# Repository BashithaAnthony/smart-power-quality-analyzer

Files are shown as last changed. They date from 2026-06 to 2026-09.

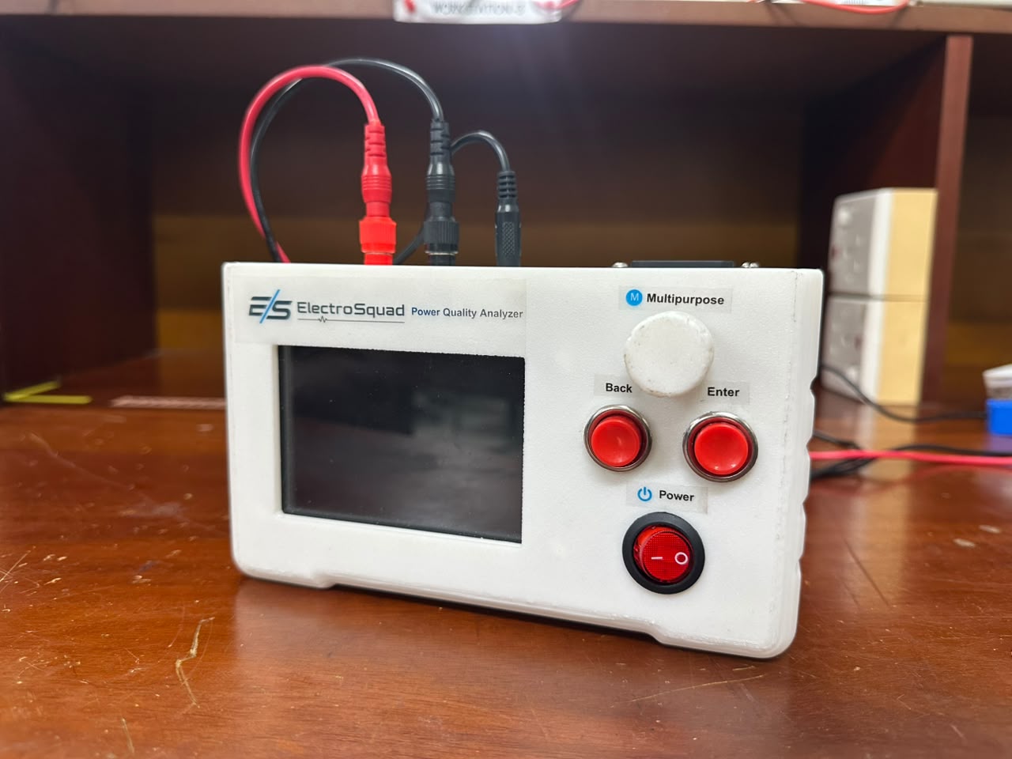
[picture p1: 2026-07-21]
media/image_1.jpeg

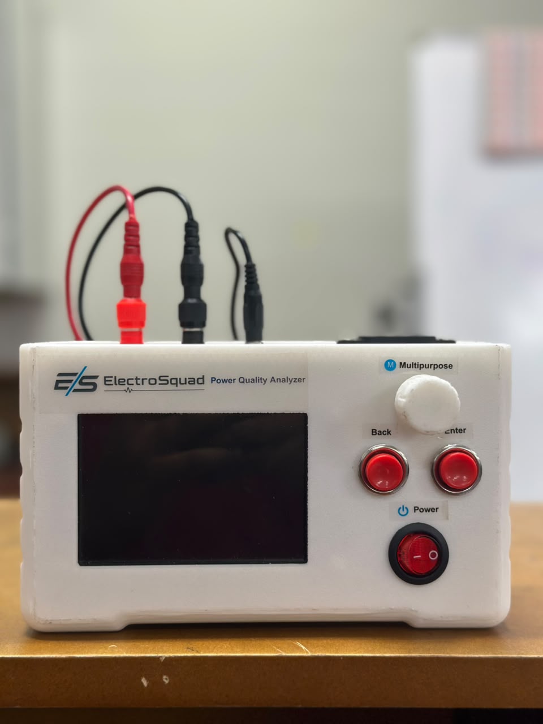
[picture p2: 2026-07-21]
media/image_3.jpeg

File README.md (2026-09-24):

# Smart Power Quality Analyzer

## Overview

The Smart Power Quality Analyzer is an embedded measurement and monitoring system developed for real-time analysis of electrical power quality in single-phase AC power systems. The device continuously acquires voltage and current waveforms, performs high-speed digital signal processing, and provides comprehensive power quality parameters through an intuitive graphical user interface and wireless monitoring platform.

The system is designed around a dual-microcontroller architecture consisting of an STM32F4 as the primary real-time processing unit and an ESP32-S3 dedicated to user interface management, wireless communication, and data visualization. By separating deterministic signal processing from networking and display tasks, the analyzer achieves high measurement accuracy while maintaining a responsive user interface.

The project combines precision analog signal conditioning, high-speed data acquisition, embedded DSP algorithms, graphical visualization, PCB design, and IoT connectivity into a single integrated platform suitable for laboratory, industrial, and educational applications.

# Key Features

## Electrical Measurements

- True RMS voltage measurement
- True RMS current measurement
- Active power calculation
- Reactive power calculation
- Apparent power calculation
- Power factor measurement
- Grid frequency measurement
- Phase angle calculation

## Power Quality Analysis

- Fast Fourier Transform (FFT) based spectral analysis
- Total Harmonic Distortion (THD) calculation
- Individual harmonic magnitude analysis
- Harmonic spectrum visualization
- Real-time waveform monitoring
- Voltage and current waveform comparison
- Continuous sampling and processing

## User Interface

- 4-inch SPI TFT LCD graphical display
- Rotary encoder based navigation
- Physical control buttons for menu navigation
- Real-time waveform rendering
- Live numerical parameter display
- Interactive graphical user interface
- Adjustable display brightness

## Connectivity

- Wi-Fi connectivity
- UART communication between STM32 and ESP32
- Remote monitoring
- Web-based dashboard
- Wireless data transfer
- MicroSD card support for future data logging

## Embedded System Features

- High-speed ADC sampling
- Real-time DSP processing
- Interrupt-driven firmware
- Multi-tasking architecture
- High-speed UART communication
- Hardware PWM control
- DMA-based data acquisition
- Efficient memory management

# System Architecture

The analyzer is divided into two independent processing sections.

## STM32F4 Processing Unit

Responsible for:

- High-speed ADC sampling
- Analog signal acquisition
- Digital filtering
- FFT computation
- RMS calculations
- Power calculations
- Harmonic analysis
- Frequency estimation
- Real-time data processing
- Communication with ESP32

## ESP32-S3 Interface Unit

Responsible for:

- LCD graphics rendering
- User interface management
- Rotary encoder handling
- Push-button interface
- Wi-Fi communication
- Web server communication
- Remote monitoring
- Data visualization
- System configuration

# Hardware Overview

## Analog Front-End

- Voltage sensing circuitry
- Current sensing circuitry
- Signal conditioning
- Precision operational amplifiers
- Anti-aliasing filters
- ADC input protection

## Processing Hardware

### STM32F4

- Primary real-time processing controller
- Digital signal processing
- High-speed ADC operation
- FFT execution
- Measurement calculations

### ESP32-S3

- Dual-core processor
- Integrated Wi-Fi
- TFT display controller
- Human-machine interface
- Wireless communication

## Display

- 4.0-inch SPI TFT LCD
- Real-time waveform visualization
- Menu-based graphical interface
- Adjustable LED backlight

## User Controls

- Incremental rotary encoder
- Enter button
- Back button
- System power control
- On-screen navigation

## Power System

- High-efficiency buck converters
- Low-noise analog supplies
- Dedicated digital power rails
- Ferrite-bead power filtering
- Controlled power sequencing
- Push-button power management

# Signal Processing

The system continuously samples voltage and current waveforms using the STM32F4 ADC.

The acquired samples undergo several DSP stages including:

- Offset correction
- Noise filtering
- Windowing
- FFT transformation
- Harmonic extraction
- RMS computation
- Frequency estimation
- Power calculations
- THD computation

The processed information is transmitted to the ESP32-S3 for visualization and wireless communication.

# Communication Architecture

## STM32 ↔ ESP32

Communication is performed through UART interface, providing reliable high-speed data transfer between the processing unit and the user interface module.

Transmitted data includes:

- Voltage samples
- Current samples
- RMS measurements
- Frequency
- Power factor
- Harmonic information
- THD values
- System status

## ESP32 ↔ User

The ESP32 provides:

- Graphical LCD interface
- Local parameter display
- Wi-Fi connectivity
- Remote monitoring capability
- Configuration interface

# PCB Design

The hardware is implemented using a custom multilayer PCB designed for mixed-signal applications.

The PCB incorporates:

- Dedicated analog and digital sections
- Controlled grounding strategy
- High-speed signal routing
- Power plane optimization
- EMI reduction techniques
- Differential USB routing
- SPI display interface
- RS-485 communication interface

# Software Stack

## STM32 Firmware

- C
- STM32CubeIDE
- HAL drivers
- CMSIS
- CMSIS-DSP
- Interrupt-driven architecture
- DMA-based ADC acquisition

## ESP32 Firmware

- Arduino Framework
- C++
- Native USB programming
- TFT graphics library
- Wi-Fi stack
- UART communication

# Development Tools

- STM32CubeIDE
- Arduino IDE
- Altium Designer
- SolidWorks

# Future Enhancements

- Three-phase power quality analysis
- Cloud connectivity
- Historical data visualization
- Energy consumption analytics
- Remote firmware updates (OTA)
- Modbus support
- USB data export
- Advanced event logging
- Configurable alarm thresholds
- Industrial communication protocols

# Current Status

**Development Status:** Finished

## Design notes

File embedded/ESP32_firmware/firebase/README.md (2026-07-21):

# Realtime Database rule deployment

Historical-session deletion follows the dashboard's existing authentication
model: any authenticated dashboard account except the dedicated ESP32 device
UID may delete a complete uploaded session. The permission exists only at the
validated `sessionIndex/s_<id>` and `sessionData/s_<id>` nodes; it does not
grant content updates or writes to live telemetry or another device path.

The website deletes one uploaded session atomically by setting only these two
locations to `null` in one multi-location update:

- `devices/PQ-3PH-001/sessionIndex/<session-key>`
- `devices/PQ-3PH-001/sessionData/<session-key>`

Rules are not deployed automatically. After reviewing and testing them, deploy
manually from the rules directory with the locally installed Firebase CLI:

```text
cd firebase
npx firebase-tools deploy --only database --project smart-power-quality-analyzer-1
```

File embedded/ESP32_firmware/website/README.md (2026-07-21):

# Power Quality Console

Authenticated React/Vite dashboard for live ESP32 telemetry and validated,
read-only historical-session graphs and waveform exports from Firebase
Realtime Database.

The historical graph view shows session measurement trends together with the
selected packet's H1–H25 voltage harmonic spectrum and H1–H25 current harmonic
spectrum. Raw waveform samples remain available only through the separate Full
Waveforms CSV export.

Sessions uploaded with a valid NTP anchor use actual measurement time on the
trend axis. Older or unanchored sessions use elapsed time from the first
retained packet and are labelled accordingly; upload timestamps are never
treated as measurement timestamps.

## Local development

1. Copy `.env.example` to `.env.local` and enter the Firebase web-app values.
2. Run `npm install`.
3. Run `npm run dev` and open the printed local URL.
4. Sign in with an authorized Firebase email/password account.

Use `VITE_HISTORY_DATA_MODE=mock` for the small deterministic historical
fixture. Firebase Authentication remains required; mock mode changes only the
historical repository and exercises the same manifest, chunk, PQR1, CRC32C,
graph, and waveform CSV pipelines.

## Checks

- `npm run typecheck`
- `npm run lint`
- `npm test`
- `npm run build`

The history routes are `/history`, `/history/:sessionKey`, and
`/history/:sessionKey/graphs`. Production SPA hosting must rewrite those
browser routes to `index.html`.

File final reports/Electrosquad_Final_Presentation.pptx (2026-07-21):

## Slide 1

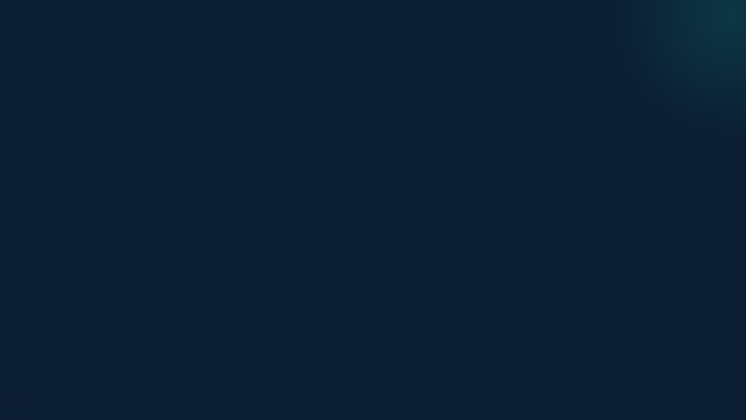
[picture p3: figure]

Smart Power Quality
Analyzer

An high-accuracy, internet-enabled instrumentation platform for electrical harmonics and metrics analysis.

- Anthony C.S.B. (230045X)
- Chandrakumara H.A.D.C. (230100M)
- Hansindu M.M.A.D. (230229P)
- Perera H.A.J.I. (230477X)
- Weerasinghe J.A.H.R. (230697V)

DESIGNED BY ELECTROSQUAD

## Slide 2

Problem & Objectives

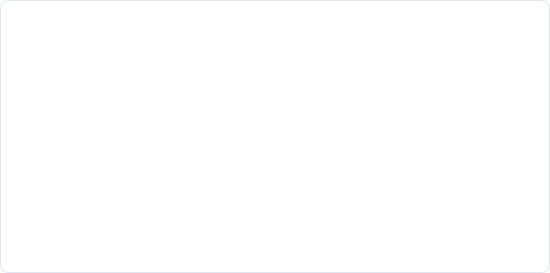
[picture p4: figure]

Power Quality Degradation

Voltage fluctuations, sags, swells, and frequency drift compromise sensitive hardware across commercial and educational grids.

Nonlinear loads generate high harmonic currents, leading to excessive thermal stresses, power grid losses, and equipment failure.

The LKR 350,000+ Barrier

Commercial high-end power analyzers range from LKR 350,000 to 1,750,000, making them completely unaffordable for SMEs and laboratories.

Goal: Engineering a low-cost, high-precision analyzer displaying local FFT data and providing remote telemetry at a fraction of the cost.

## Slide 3

Technical Specifications

Parameter | Device Specification | Details & Protocol
System Type | Single-Phase Power-Quality Analyzer | Designed for industrial/domestic monitoring
Nominal Grid Voltages | 230 V AC nominal | 0 - 300 V AC Range | Adapts to broad fluctuation limits
Nominal Line Frequency | 50 Hz Base Frequency | Real-time detection and logging
Current Measurement Range | 0 to 50 A max measurement limit | SCT-013-050 non-invasive sensor support
Harmonics Analysis range | 1st to 25th Harmonic Order (H1 to H25) | High-speed simultaneous sampling FFT
MCU Inter-comm Rate | 921,600 bps high-speed UART link | Minimal packet delivery latency (DMA-backed)
Wireless Link & DB | 2.4 GHz Wi-Fi to Firebase Cloud Platform | Live database sync and historic CSV tracking

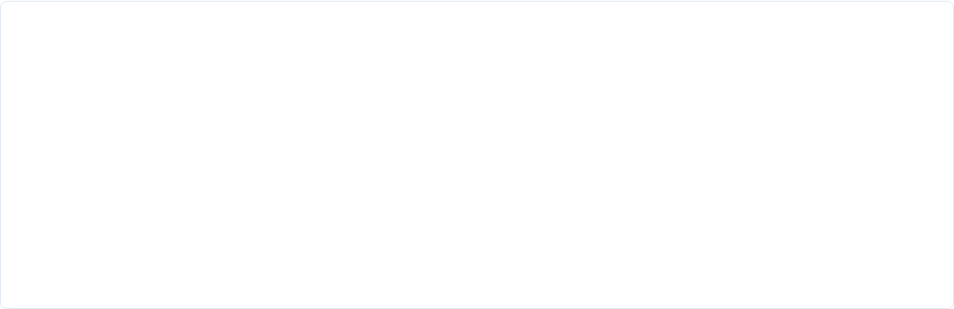
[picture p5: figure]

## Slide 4

System Architecture

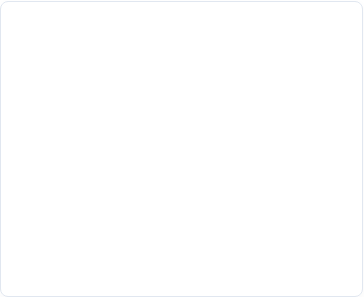
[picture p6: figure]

Sensing & Isolation

Voltage: High-precision divider mapped to an isolated AMC1301 amplifier.

Current: SCT-013-050 sensor provides galvanic isolation with precise burden calibration.

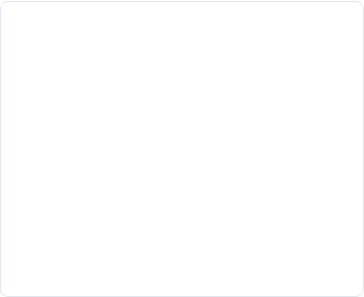
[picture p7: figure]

Acquisition & processing

16-bit external ADS8588 ADC reads signals concurrently over SPI at 10 kHz.

STM32F411 processes 1024-point frames using CMSIS-DSP to calculate RMS, THD, and FFT.

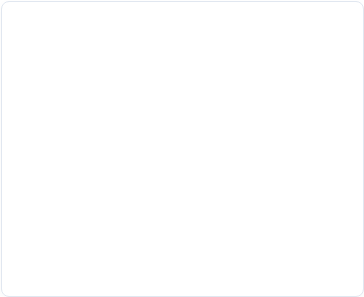
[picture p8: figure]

Interface & Telemetry

ESP32-S3 parses packet arrays over 921,600 bps UART.

Drives localized 7" touch TFT screen and streams encrypted telemetry into Firebase Realtime Database.

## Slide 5

System Architecture

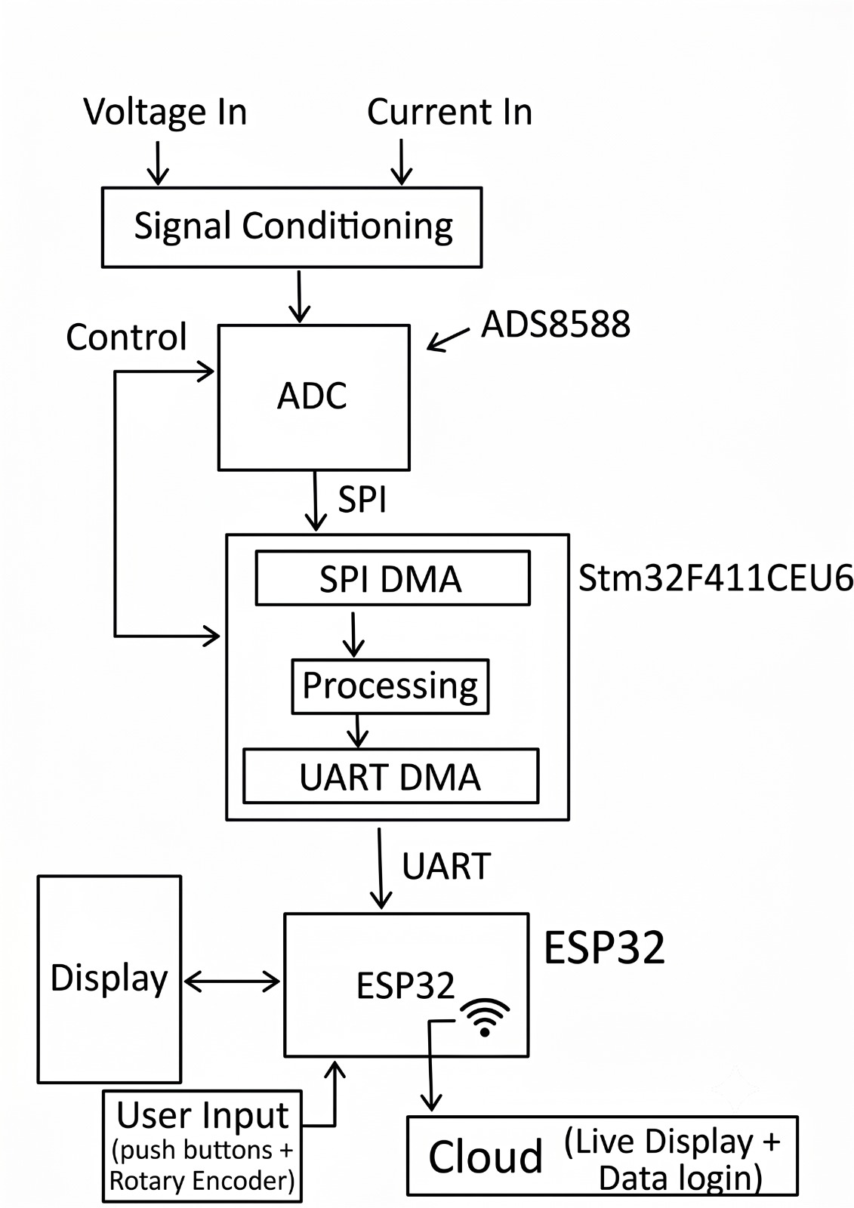
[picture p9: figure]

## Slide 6

Hardware: PCB Design

Signal Isolation Schemes

To safely bridge high 230V AC mains voltage to low-voltage MCU digital rails, we integrated AMC1301 isolation amplifiers.

The layout enforces a clear physical gap between primary high-voltage areas and sensitive signal processing traces.

Traces, Filters, and Grounds

Dedicated two-layer board design with solid independent analog/digital ground fills to prevent high-frequency noise insertion.

All ADC inputs include inline RC decoupling networks to protect the external 16-bit ADS8588 analog pins from signal reflection.

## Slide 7

Hardware: PCB Design

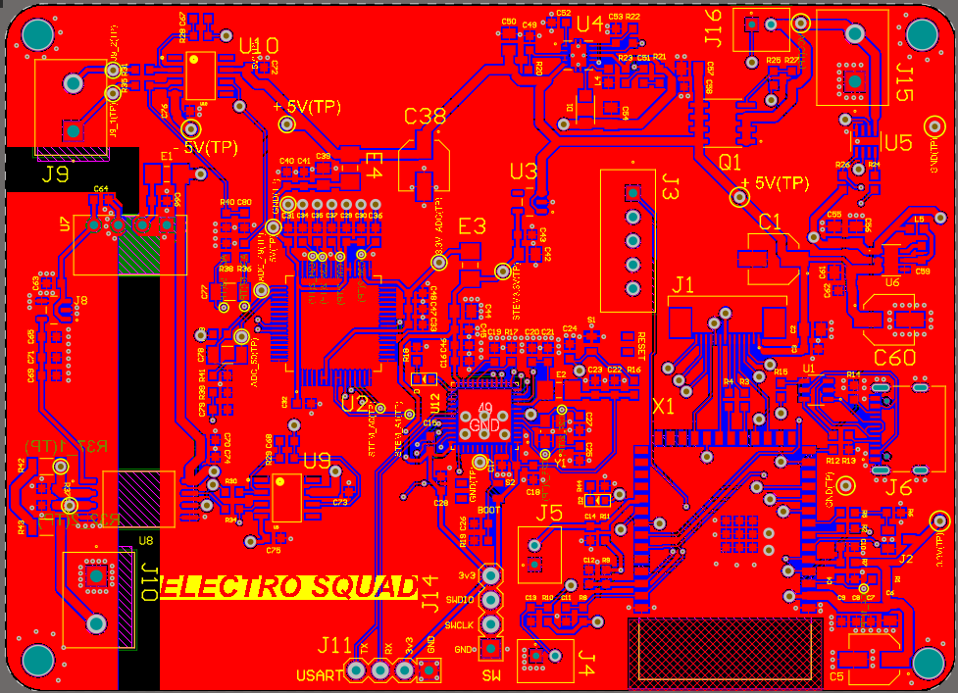
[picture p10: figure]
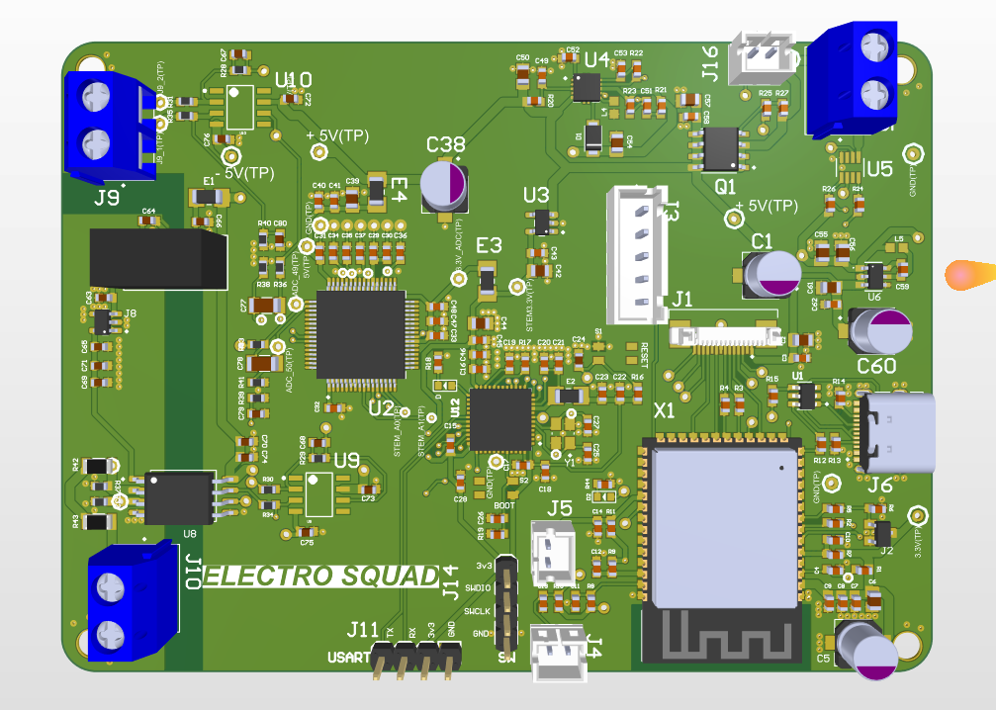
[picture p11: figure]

Front View - 2D

Front View - 3D

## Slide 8

Hardware: Enclosure

Mechanics & Sizing

Form Factor: Highly durable, compact desk-ready enclosure matching industrial workbench criteria.

Dimensions: 9 inches width, 6 inches height, and a 2.5 inches depth profile.

Safety Integration: Features integrated ventilation slots for cooling, keeping standard system temperatures low.

Human-Machine Interfaces

Local Screen: Center-mounted high-contrast TFT color touchscreen powered via an FT6336 controller.

Tactile Controls: Hardwired rotary encoder and dedicated push-buttons for logging control and screen navigation.

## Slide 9

Hardware: Enclosure

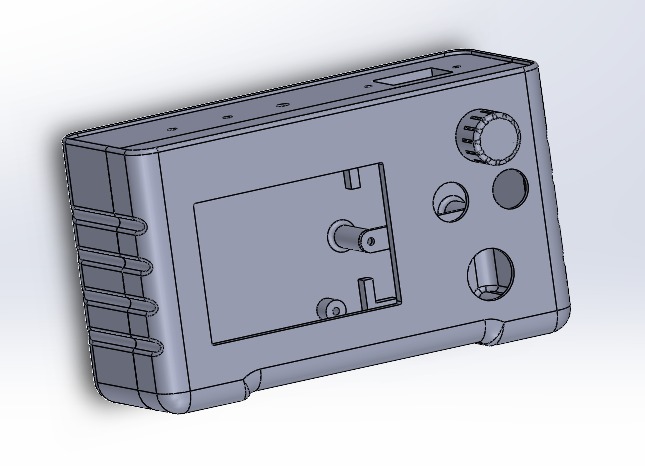
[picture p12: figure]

Front View

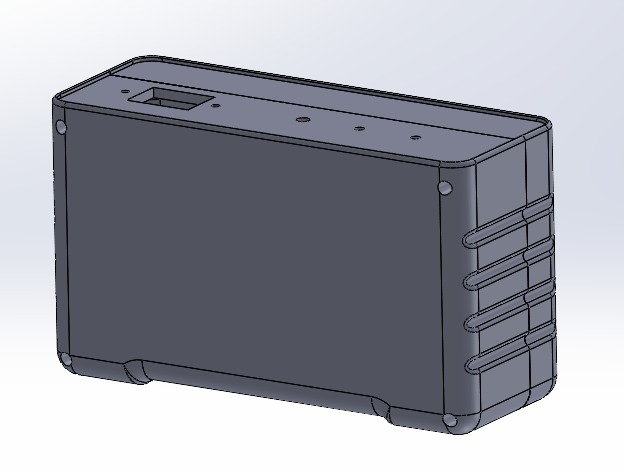
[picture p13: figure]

Back View

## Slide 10

Firmware & Processing

Simultaneous 10 kHz Sampling: SPI interface driven by DMA sweeps external 16-bit ADS8588 analog values at precise intervals to guarantee zero phase delays between signals.

CMSIS-DSP Execution: The STM32F411 processes 1024 raw data samples every 102.4 ms, using hardware floating-point acceleration to maintain strict real-time deadlines.

Parametric Calculations: Computes real-time True RMS Voltages, Currents, Active Power, Reactive Power, Apparent Power, Supply Frequency, and Power Factor.

Harmonics & THD: Solves 25-point FFT decompositions on voltage and current profiles, calculating precise Total Harmonic Distortion (THD) ratios up to order H25.

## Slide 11

IoT Cloud Dashboard

Real-Time IoT Telemetry

Using Vite, React, and TypeScript, the web dashboard displays real-time system metrics directly from Firebase Realtime Database.

Automatically triggers visual alerts and warning codes if voltage sags, swells, or high THD conditions are detected.

Session Archives & Analysis

The dashboard lists all historical test periods synced from the analyzer's local storage.

Enables single-click downloads of complete measurements in CSV format, facilitating immediate integration with MATLAB or Excel.

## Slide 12

IoT Cloud Dashboard

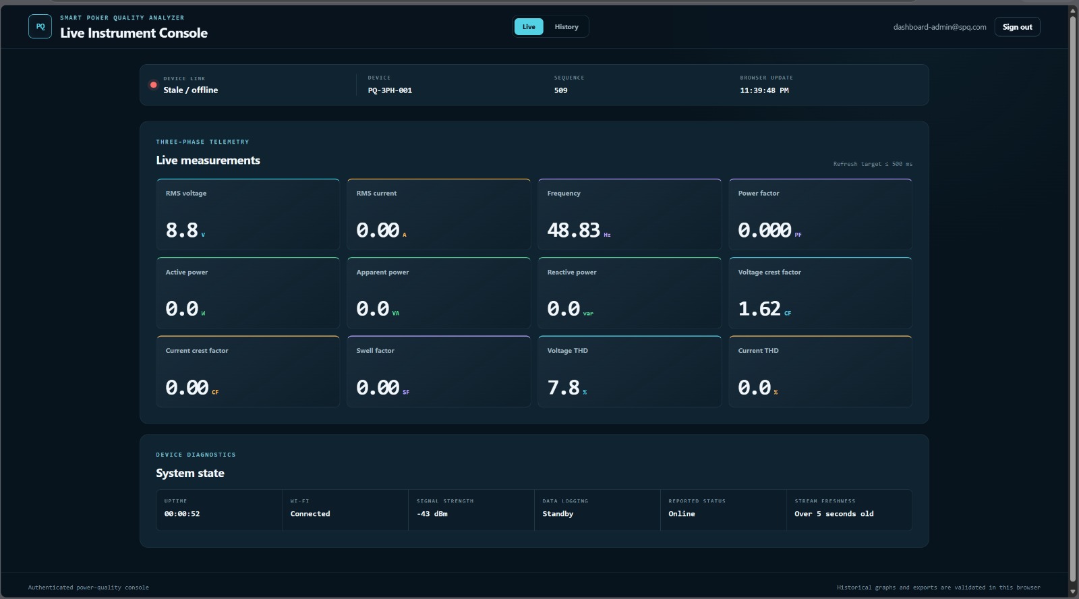
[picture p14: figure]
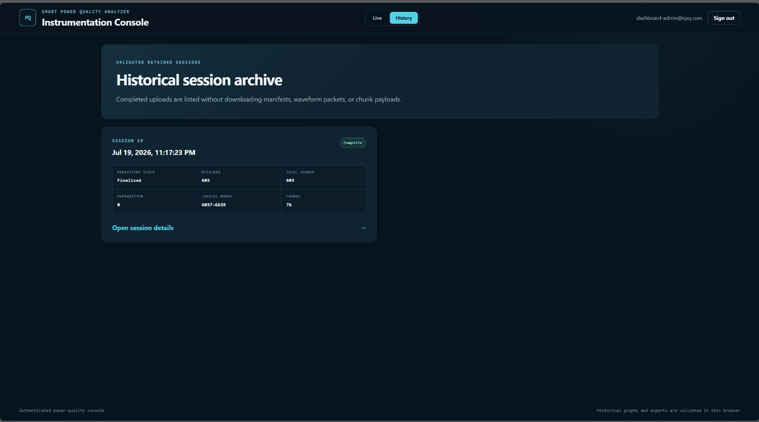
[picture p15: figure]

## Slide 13

Harmonics & Distortion

The analyzer successfully isolates and tracks dominant 3rd, 5th, and 7th harmonic profiles, aligning precisely with high-end commercial references under heavy distortion loads.

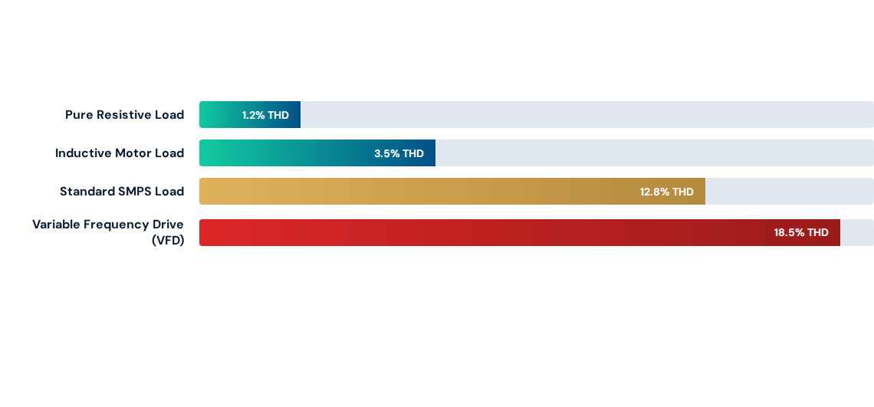
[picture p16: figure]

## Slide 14

Project Budget & Costing

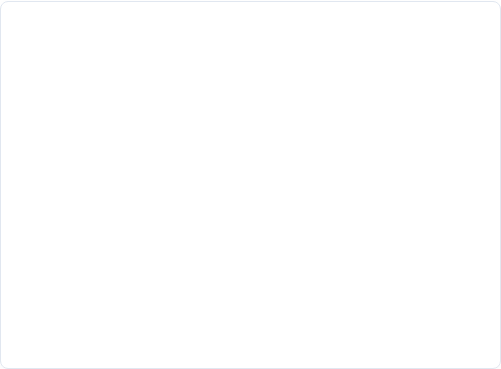
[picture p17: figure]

No. | Bill of Quantities (BoQ) | Cost (LKR)
1 | General Electronic Components | 12,773
2 | 7" Color TFT Display Module | 6,000
3 | Cables, Terminals, Connectors | 2,000
4 | Enclosure Assembly Parts | 3,000
5 | AC-DC Isolated Supply Module | 1,450
6 | Two-Layer PCB Manufacturing | 8,000
- | Estimated Total Cost | 33,223

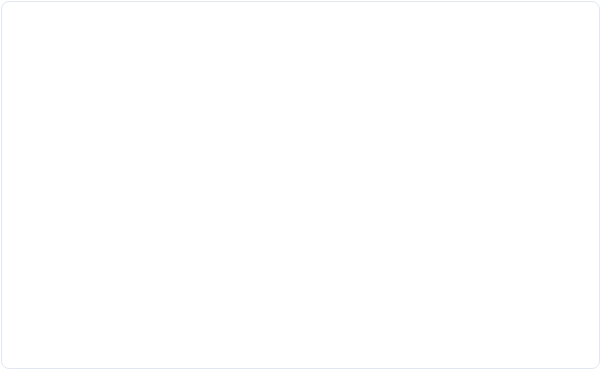
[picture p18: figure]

Total Cost Equation

Our target selling price of $300 (~LKR 90,000) delivers a highly viable profit margin while undercutting commercial analyzers by over 70%.

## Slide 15

Market Readiness Metrics

Safety Compliance

Fully compliant with IEC 61000 and IEEE 1159 electrical safety guidelines.

High dielectric barrier protection ensures complete low-voltage user isolation during mains failures.

Enclosure Durability

Constructed with flame-retardant structural plastic.

Compact, durable desktop form factor with optimized air ventilation allows for reliable continuous operation.

Target Markets

An ideal tool for educational laboratories, SMEs, and grid technicians.

Enables affordable energy audits and continuous power quality assessment.

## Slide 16

Conclusion & Future Work

Project Milestones Achieved: Realized a highly accurate, internet-enabled, single-phase analyzer. Successfully completed all hardware isolation tests and remote dashboard streaming pipelines.

Three-Phase Expansion: Upgrading core hardware to enable simultaneous, high-precision measurement of three-phase voltage and current lines.

Cloud Analytics & Alerts: Integrating serverless machine learning loops to automatically classify power quality issues (sags, swells, transients) and alert operators.

Mobile App Ecosystem: Developing dedicated Android and iOS companion apps using Bluetooth and local Wi-Fi for quick on-the-go checks.

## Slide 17

THANK YOU

ELECTROSQUAD

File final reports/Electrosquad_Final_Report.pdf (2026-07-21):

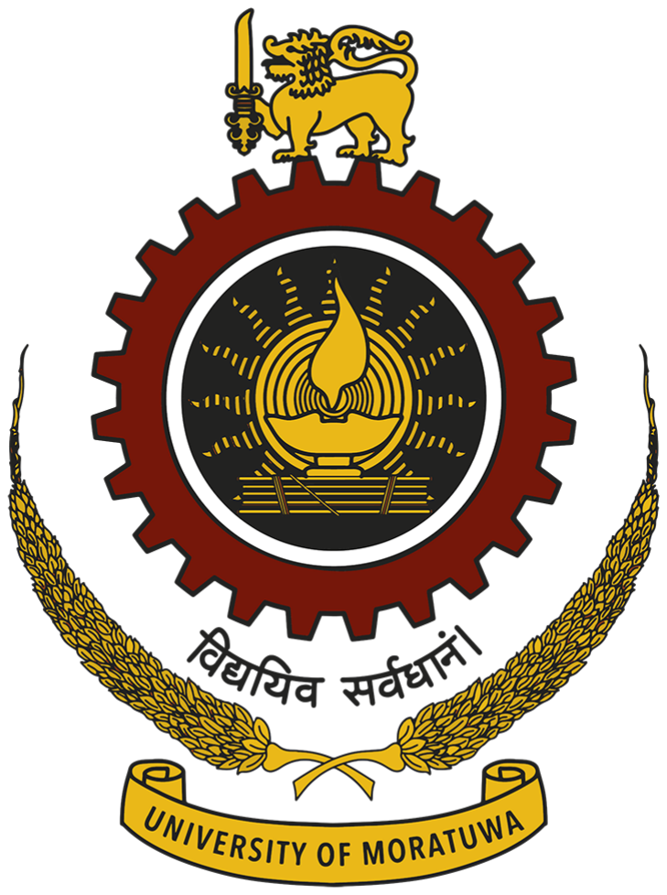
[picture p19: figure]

Department of Electronic & Telecommunication Engineering University of Moratuwa
Sri Lanka.

## Project Report

## Smart Power Quality Analyzer

## EN2160 - Electronic Design Realization

Group Name: ElectroSquad

Anthony C.S.B. | : 230045X
Chandrakumara H.A.D.C. | : 230100M
Hansindu M.M.A.D. | : 230229P
Perera H.A.J.I. | : 230477X
Weerasinghe J.A.H.R. | : 230697V

Date: 20-07-2026

Smart Power Quality Analyzer - Project Report | ElectroSquad

Contents

Smart Power Quality Analyzer - Project Report | 4
1 Problem Description, Justification and Benefits of Our Solution | 4
2 Technical Feasibility | 5
3 Technical Specification | 6
4 Product Architecture | 7
5 Initial and Final Sketches of Product Enclosure | 9
6 Schematic and PCB Design | 11
7 UI Design | 14

8 Sales and Maintenance | 15
9 Volume Production and Product Costing | 16
10 Project Budget with Bill of Quantities | 17
11 Task Allocation | 19

Smart Power Quality Analyzer - Project Report

### 1 Problem Description, Justification and Benefits of Our Solution

### 1.1 Problem Description

Modern electrical systems frequently experience power-quality problems such as voltage sags, voltage swells, harmonic distortion, poor power factor, and frequency variations. These problems can reduce equipment performance, increase energy losses, shorten equipment lifetime, and cause unexpected failures.

Commercial power-quality analyzers are often expensive and may not be affordable for small industries, laboratories, educational institutions, and domestic users. Therefore, there is a need for a low-cost and user-friendly system capable of monitoring important electrical parameters in real time.

### 1.2 Our Solution

The proposed solution is a Smart Power Quality Analyzer that measures, processes, displays, stores, and remotely presents important power-quality parameters.

The system is designed to monitor:

- RMS voltage;
- RMS current;
- frequency;
- active power;
- reactive power;
- apparent power;
- power factor;
- voltage THD;
- current THD;
- voltage harmonics from H1 to H25;
- current harmonics from H1 to H25; and
- voltage and current waveforms.

### 1.3 Justification

The proposed system is justified by the need for an affordable, accessible, and portable power-quality monitoring solution. In the Sri Lankan context, rising energy costs, limited access to expensive test equipment, and the increasing use of nonlinear electrical loads create a clear need for such a device.

The system combines local monitoring through a TFT display with remote monitoring through a web dashboard. This makes the device suitable for educational, industrial, laboratory, and domestic applications.

### 1.4 Benefits of Our Solution

- Early detection of abnormal electrical conditions.
- Improved protection of electrical and electronic equipment.
- Better understanding of energy consumption.
- Real-time local and remote monitoring.
- Lower cost than commercial analyzers.
- Availability of logged data for later analysis.
- Easy access to completed sessions through CSV files.
- Suitability for educational and small-scale industrial use.

### 2 Technical Feasibility

### 2.1 Hardware Feasibility

The system uses commonly available microcontrollers and electronic components. The STM32 controller is used for signal acquisition and electrical calculations, while the ESP32-S3 is used for display control, Wi-Fi communication, Firebase integration, and data logging. For better accuracy, a 16-bit external ADC is used rather than the internal STM ADC.

The main hardware components include:

- STM32 microcontroller
- ESP32-S3 microcontroller
- ADS8588 ADC
- voltage-sensing circuit
- current-sensing circuit
- TFT colour display
- FT6336 touch controller
- rotary encoder and control buttons
- power-supply circuit
- printed circuit board
- protection components
- product enclosure.

### 2.2 Software Feasibility

The firmware was developed using standard embedded system development tools, while the web dashboard was implemented using React, TypeScript and Vite. Firebase Realtime Database was used to store and retrieve live measurements and logged data in CSV format. The use of Firebase also enabled the deployment of a hosted web platform in which each analyzer can be identified through a unique device ID and accessed only through authorized email accounts assigned to that device.

### 2.3 Operational Feasibility

The system is designed to be simple to operate. The user can view live measurements on the TFT screen, navigate through waveform and harmonic screens, start and stop logging, synchronize completed sessions, and view data remotely through the dashboard.

### 2.4 Economic Feasibility

The proposed analyzer is expected to cost significantly less than commercial power quality analyzers. The design uses affordable and widely available components while still providing the main features required for real time monitoring and data logging.

### 3 Technical Specification

Table 1: Technical specifications of the proposed analyzer

Parameter | Specification
System type | Single-phase power-quality analyzer
Nominal voltage | 230 V AC
Nominal frequency | 50 Hz
Voltage measurement range | 0-300 V
Current measurement range | 0-50 A
Harmonic measurement range | H1 to H25
UART baud rate | 921600 bits per second
Local display | TFT colour display
Wireless communication | Wi-Fi
Cloud platform | Firebase Realtime Database
Local storage | ESP32-S3 flash memory
Data-export format | CSV

### 3.1 Measured Parameters

Table 2: Measured and calculated electrical parameters

Parameter | Unit | Description
RMS voltage | V | Effective value of the measured voltage
RMS current | A | Effective value of the measured current
Frequency | Hz | Fundamental frequency of the supply
Active power | W | Real power consumed by the load
Reactive power | var | Reactive component of power
Apparent power | VA | Product of RMS voltage and RMS current
Power factor | – | Ratio of active power to apparent power
Voltage THD | % | Total harmonic distortion of voltage
Current THD | % | Total harmonic distortion of current
Voltage harmonics | % | Harmonic magnitudes from H1 to H25
Current harmonics | % | Harmonic magnitudes from H1 to H25

### 4 Product Architecture

### 4.1 Overall Architecture

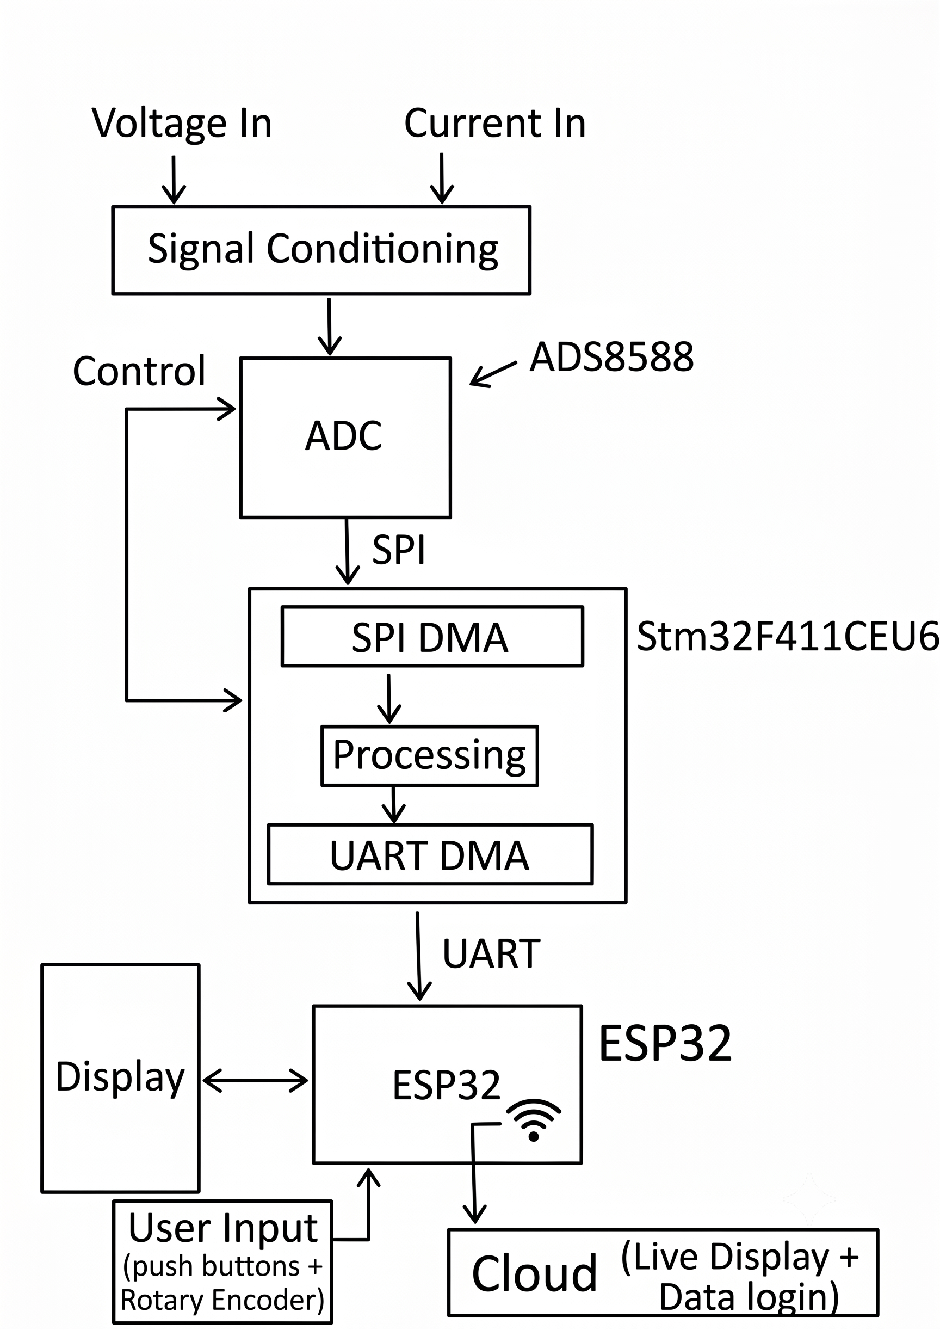
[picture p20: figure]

Figure 1: Overall product architecture

### 4.2 Voltage-Sensing Unit

The voltage-sensing unit uses a precision resistor divider to step down the mains voltage to a 250 mV differential signal. To ensure safety, the PCB segregates the circuitry into an isolated ground plane (referenced to mains neutral) and a main system ground plane. An AMC1301 isolation amplifier bridges these planes, providing galvanic isolation while transmitting the 250 mV signal. An OPA197 operational amplifier then acts as a differential amplifier to apply a precise gain, optimizing the signal for the maximum dynamic range of the ADS8588 ADC. Finally, a symmetric low-pass anti-aliasing filter removes high-frequency noise prior to digitization.

### 4.3 Current-Sensing Unit

The current-sensing unit measures load current using an SCT-013-050 current transformer. Because the sensor inherently provides galvanic isolation, its output is referenced directly to the main system ground plane of the PCB. This signal is routed to an OPA197 operational amplifier configured as a differential amplifier, which applies the specific gain required to utilize the optimal maximum range of the ADS8588 ADC. The output is then passed through a symmetric low-pass anti-aliasing filter directly to the ADC to ensure clean and accurate signal conversion.

### 4.4 STM32 Processing Unit

The STM32 microcontroller controls the ADC to sample voltage and current signals at a sampling frequency of 10 kHz. The digitized samples are acquired via the SPI interface. Every 102.4 ms, after collecting 1024 samples of both voltage and current, the microcontroller processes the data to compute various electrical parameters, including voltage RMS, current RMS, active power, apparent power, reactive power, power factor, frequency, voltage and current crest factors, swell factor, voltage and current total harmonic distortion (THD), and voltage and current harmonic magnitudes up to the 25th order. To improve computational efficiency and achieve real-time performance, the CMSIS-DSP library was utilized for the signal processing and mathematical computations. Upon completion of the calculations, the resulting measurement data is packaged and transmitted to the ESP32 microcontroller via UART at a baud rate of 921600 bps.

### 4.5 ESP32-S3 Unit

The ESP32-S3 receives processed data from the STM32 through UART. It validates the packet header, length, sequence number, and checksum before displaying or publishing the data.

- TFT display;
- touch input;
- rotary encoder and buttons;
- Wi-Fi connection;
- Firebase communication;
- flash-memory logging; and
- synchronization of completed sessions.

### 4.6 UART Communication

Table 3: UART connection between STM32 and ESP32-S3

STM32 Pin | ESP32-S3 Pin | Function
PA11 | RX | STM32 transmission to ESP32-S3
PA12 | TX | ESP32-S3 transmission to STM32
GND | GND | Common ground
3.3 V | 3.3 V | Supply where applicable

### 4.7 Data Flow

1. Voltage and current signals are sensed.
2. The STM32 samples and processes the signals.
3. Calculated values, waveforms, and harmonics are placed in a UART packet.
4. The ESP32-S3 receives and validates the packet.
5. Valid data are displayed on the TFT screen.
6. Selected live values are uploaded to Firebase.
7. The web dashboard retrieves and displays the latest measurements.
8. Logging data are stored and later exported as CSV files.

### 5 Initial and Final Sketches of Product Enclosure

### 5.1 Initial Sketches

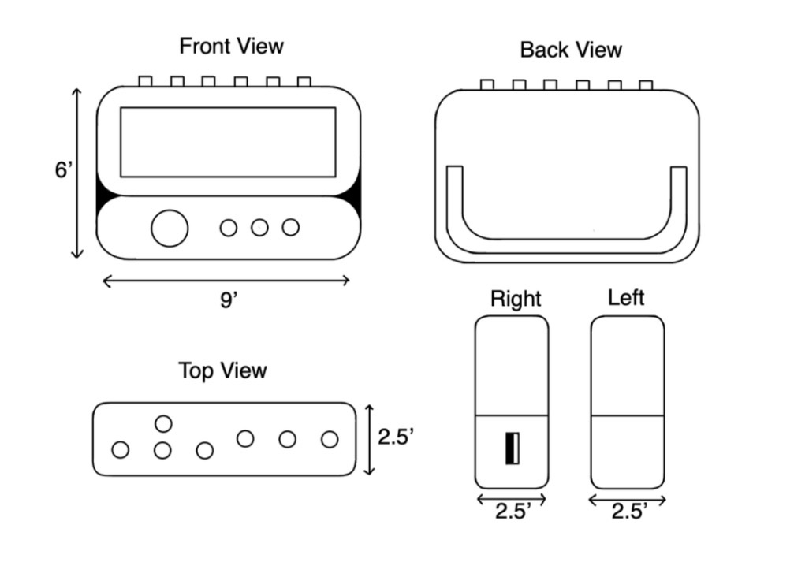
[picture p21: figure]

Figure 2: Initial Enclosure Sketches

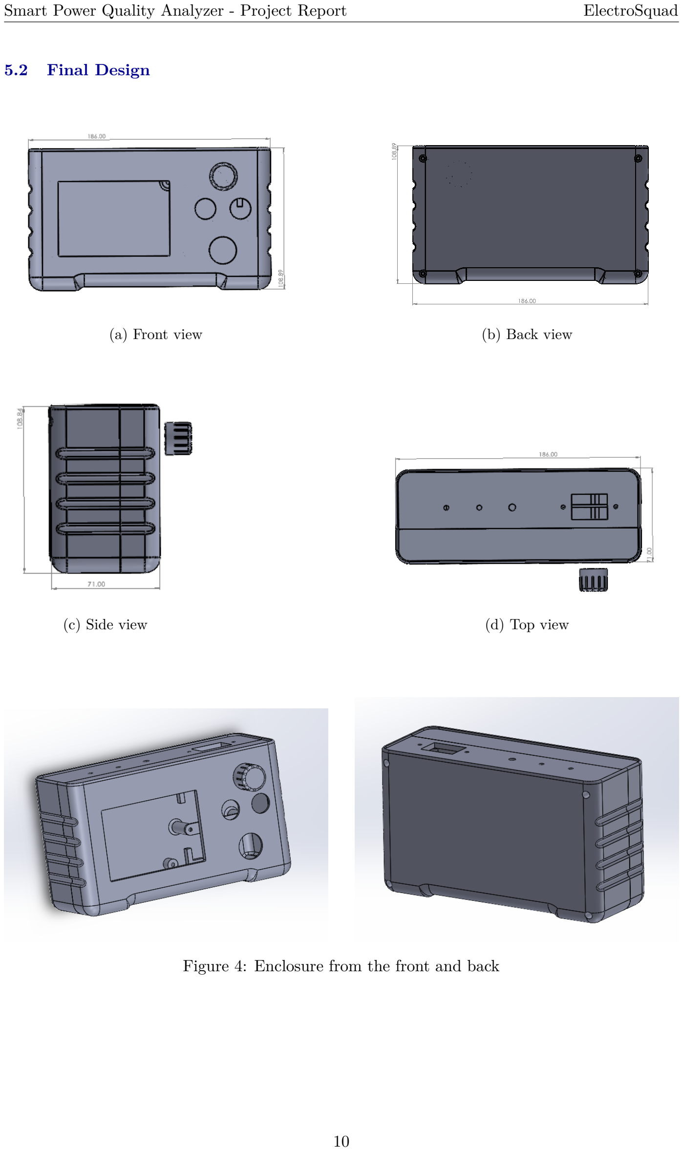
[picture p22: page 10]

### 5.2 Final Design

(a) Front view | (b) Back view
(c) Side view | (d) Top view

Figure 4: Enclosure from the front and back

### 6 Schematic and PCB Design

### 6.1 Schematic Design

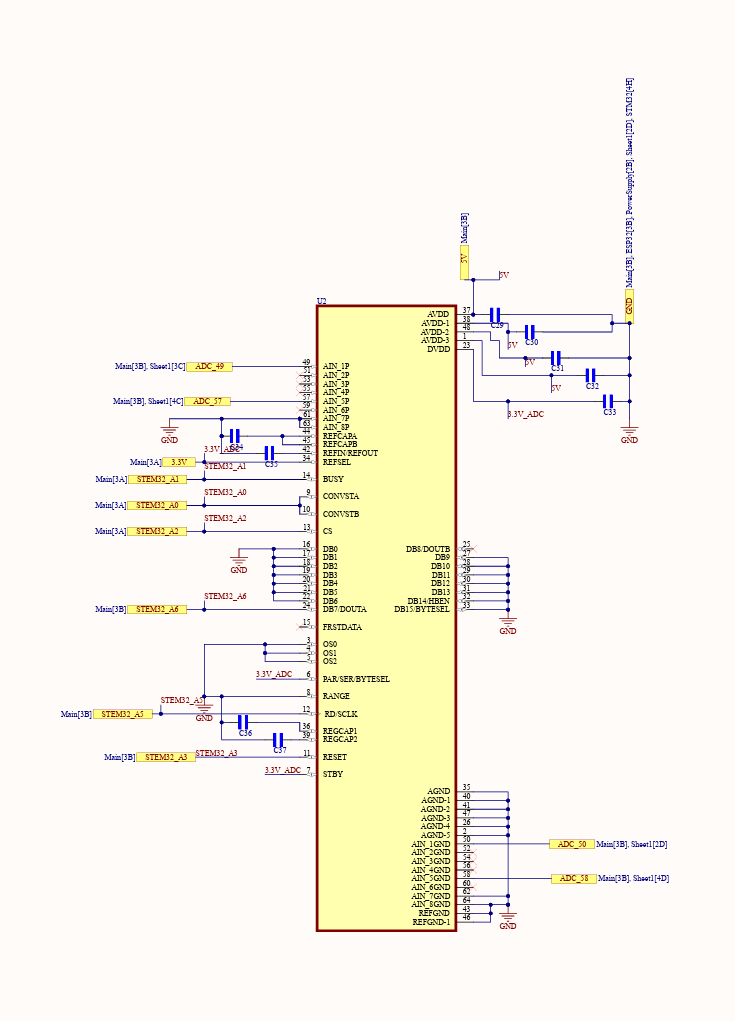
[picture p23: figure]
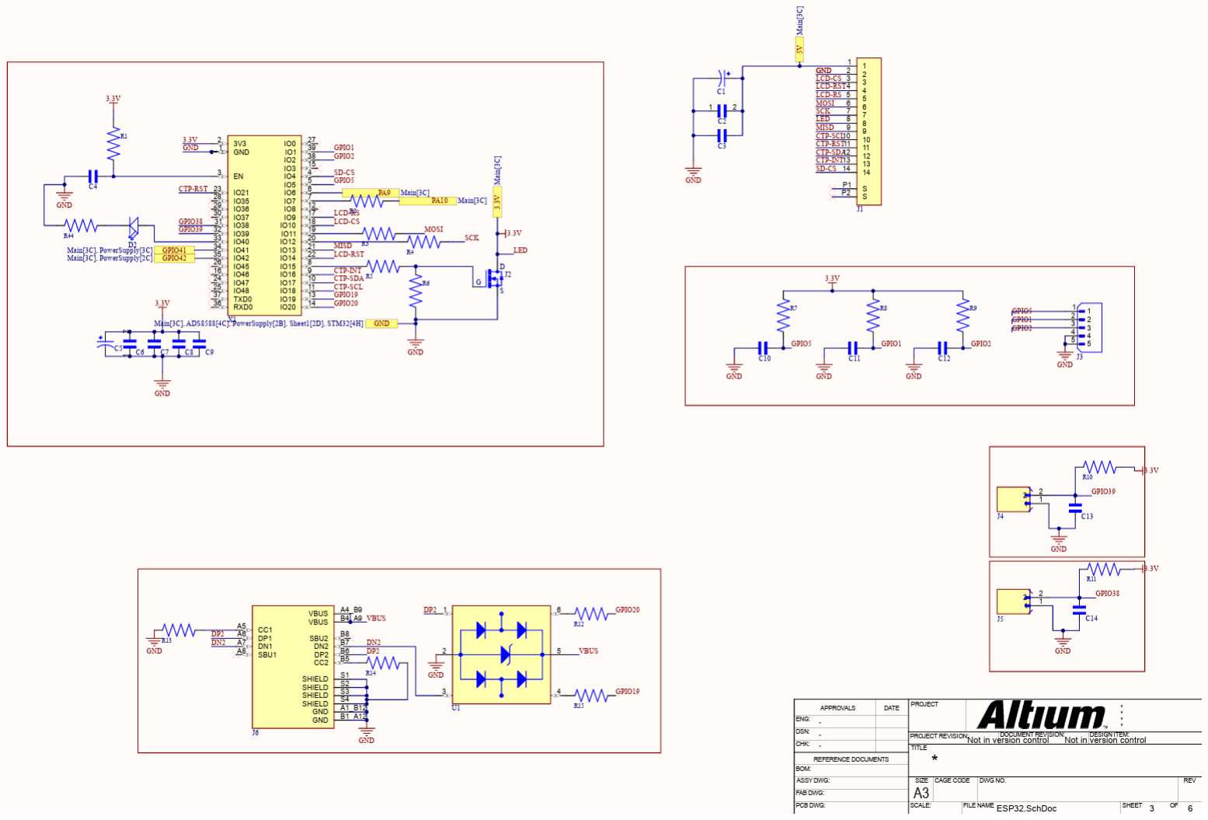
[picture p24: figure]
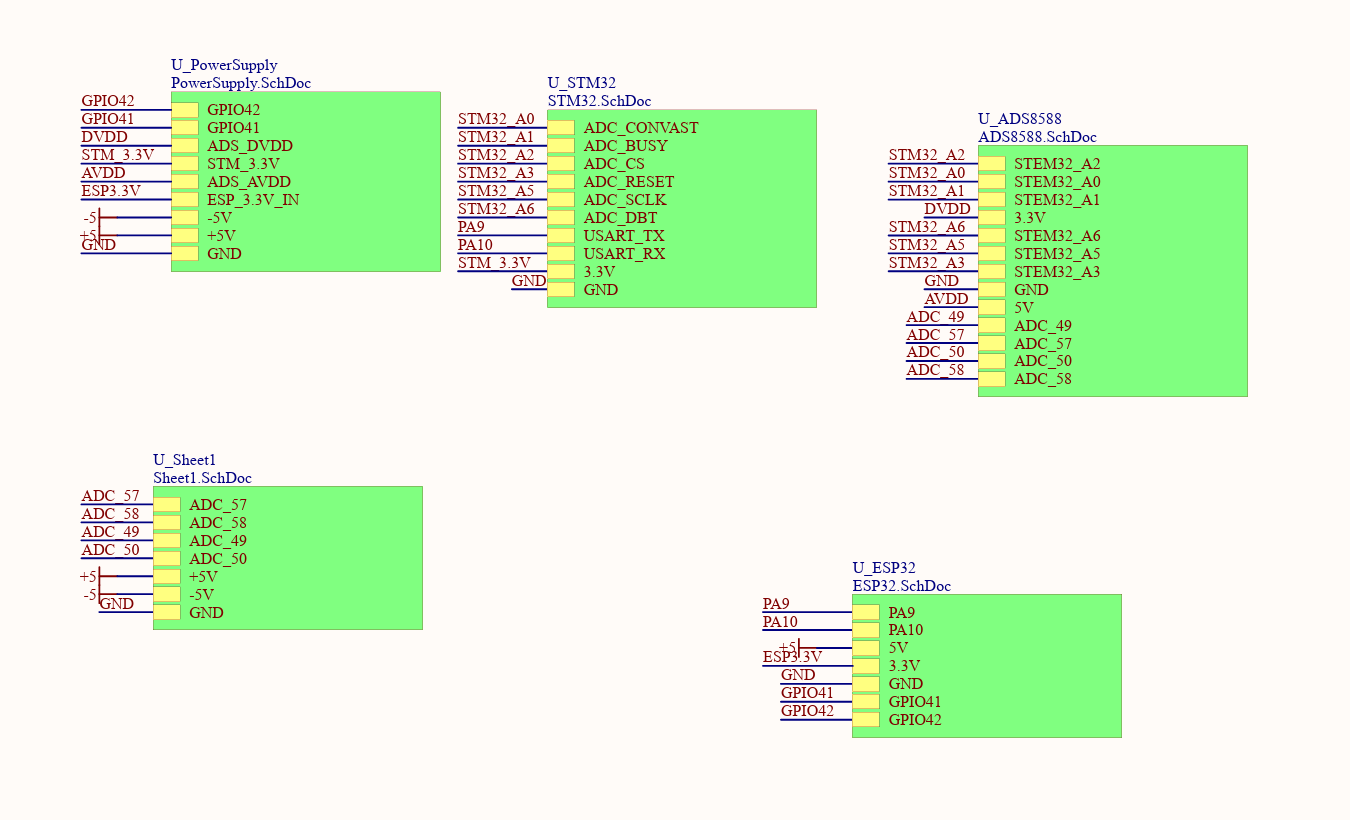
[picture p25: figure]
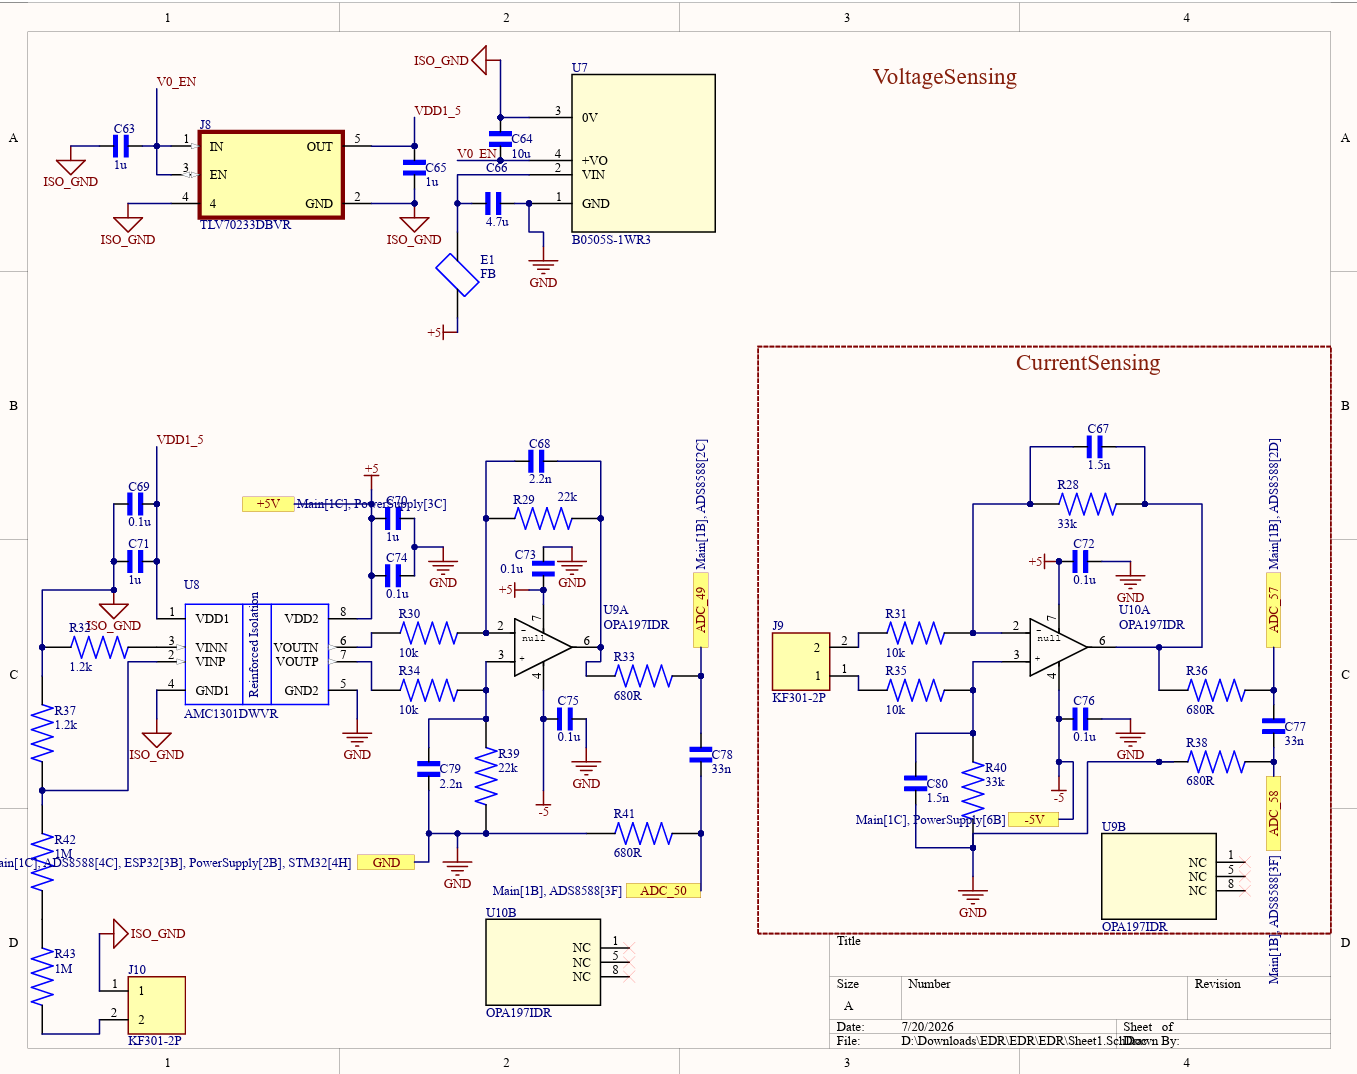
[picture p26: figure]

Figure 5: Complete schematic sheets of the Smart Power Quality Analyzer

### 6.2 PCB Design


(a) Two-dimensional top view | (b) Two-dimensional bottom view


(c) Three-dimensional top view | (d) Three-dimensional bottom view

Figure 6: Two-dimensional and three-dimensional views of the PCB design

The two-dimensional views show the component placement, copper routing, ground planes, vias, and board outline on the top and bottom layers. The three-dimensional views were used to inspect component orientation, mechanical clearance, connector positions, and the overall physical arrangement of the assembled PCB.

### 6.3 PCB Design Features and Design Justification

1. Functional Subsystem Zoning
Components are grouped strategically by function—including the power supply, ESP32, STM32, ADC, and analog acquisition stages—to minimize routing complexity, shorten interconnects, and optimize structural layout.
2. Mixed-Signal Isolation
Analog acquisition and ADC stages are physically isolated from high-speed digital domains (ESP32, STM32, and LCD interfaces) to mitigate electromagnetic interference (EMI) and cross-talk, preserving measurement accuracy.
3. Decoupled Power Domain Distribution
Independent, regulated power networks service distinct subsystems: a buck converter powers the ESP32, an LDO drives the STM32, and ferrite bead filtering isolates the analog ADC rail to ensure stable, low-noise supply lines.
4. Minimized Switching Loop Geometry
Buck converter topologies feature tight, clustered component placement to shrink high-current switching loops, reducing radiated switching noise, EMI, and parasitic power losses.
5. Short-Path Analog Topology
The ADS8588 ADC is positioned immediately adjacent to the signal conditioning circuitry to keep analog traces as short as possible, preventing noise pickup prior to digitization.
6. Localized Decoupling Network
Decoupling capacitors are placed at the immediate power pins of each integrated circuit to enhance power integrity by dampening transient voltage fluctuations.
7. Low-Impedance Return Paths and Via Stitching
Dual-layer ground polygon pours integrated with dense via stitching establish low-impedance return paths, optimizing current flow, lowering EMI, and stabilizing signal integrity.
8. Antenna Keep-Out Constraints
A dedicated, copper-free keep-out zone is maintained beneath the ESP32 antenna structure in compliance with vendor specifications to prevent RF detuning and maximize wireless performance.
9. Low-Loss Power Trace Geometry
High-current paths utilize widened trace geometries to diminish parasitic voltage drops, minimize internal power dissipation, and improve overall thermal efficiency.
10. High-Speed Critical Signal Routing
Critical high-speed lines, such as the STM32-to-ADS8588 SPI interface, are routed via short, direct trajectories over unbroken, continuous ground reference planes to preserve signal integrity.
11. Aggressive Aggressor Isolation
Known noise aggressors—such as switching regulators, USB interfaces, Wi-Fi modules, and LCD backlight circuitry—are placed away from sensitive analog measurement zones to block radiated and conducted interference.
12. Diagnostic Test Point Integration
Dedicated test points populate critical power rails, communication buses, and analog nodes to streamline voltage verification, signal diagnostics, and system debugging.
13. Peripheral Accessibility and Ergonomics
Human-machine interface (HMI) components, including display headers, USB ports, rotary encoders, and tactical switches, are aligned along the PCB perimeter for streamlined assembly and user interaction.
14. Thermal Dissipation Management
Thermal-generating elements like switching regulators are positioned near the board edge alongside expansive copper planes to accelerate heat dissipation away from temperaturesensitive analog components.
15. Electromagnetic Compatibility (EMC) Optimization
Strict enforcement of tight loop areas, continuous reference planes, shortened return paths, and explicit mixed-signal segregation ensures robust EMC performance and reliable hardware operation.

### 7 UI Design

### 7.1 TFT User Interface

Table 4: TFT screen functions

Screen | Function
Main | measurement
screen

Displays important scalar measurements

Voltage | waveform
screen

Displays the sampled voltage waveform

Current | waveform
screen

Displays the sampled current waveform

Voltage | harmonics
screen

Displays voltage harmonics from H1 to H25

Current harmonics
screen

Displays current harmonics from H1 to H25

Logging screen | Provides Start Log, Stop Log, and Push Sync controls
Wi-Fi screen | Displays connection and configuration information
Settings screen | Provides device settings and configuration options

### 7.2 Physical Controls

The physical controls include a rotary encoder, push buttons, and touch input. These controls allow the user to navigate between screens, start and stop logging, and synchronize stored data.

### 7.3 Web Dashboard

- Voltage.
- Current.
- Frequency.
- Power factor.
- THD.
- Active power.
- Device connection status.
- Warning and normal states.
- Trend graphs.
- Logging status.
- Completed sessions.
- CSV-download options.


(a) Live update web dashboard | (b) Log page in Website

Figure 7: Web Interface

### 7.4 Operating Procedure

1. Apply power to the analyzer.
2. Wait for the STM32 and ESP32-S3 to initialize.
3. Verify that live measurements are displayed.
4. Navigate through waveform, harmonic, and measurement screens.
5. Open the logging screen when data logging is required.
6. Press Start Log.
7. Press Stop Log when the required period is complete.
8. Press Push Sync to synchronize the session.
9. Access the web dashboard and download the CSV file.

### 8 Sales and Maintenance

### 8.1 Target Customers

- Educational laboratories.
- Small and medium-scale industries.
- Electrical technicians.
- Maintenance engineers.
- Energy auditors.
- Research laboratories.
- Domestic users.
- Renewable-energy system operators.

### 8.2 Sales Strategy

The product can be sold directly to educational institutions, laboratories, small industries, and technicians. Online platforms and an official product website may also be used for sales.

### 8.3 Packaging

- Product name.
- Product image.
- Technical specifications.
- Serial number.
- Manufacturing date.
- Safety instructions.
- QR code.
- Warranty details.
- Contact information.

### 8.4 Maintenance

The device should be periodically calibrated to maintain measurement accuracy. Firmware updates may be provided when improvements are made. Replaceable parts should be used wherever possible to simplify maintenance.

### 8.5 Repair and Warranty

A suitable warranty period should be provided. During the warranty period, manufacturing defects and technical faults should be repaired or the unit should be replaced when necessary.

### 9 Volume Production and Product Costing

### 9.1 Considerations for Volume Production

When the product enters volume production, the following factors should be considered:

- Bulk purchasing of electronic components to reduce material cost.
- Automated PCB assembly and testing to improve production efficiency.
- Standardized manufacturing processes to ensure consistent product quality.
- Design for Manufacturability (DFM) to simplify assembly and reduce production time.
- Quality control and calibration of every unit before shipment.
- Compliance with electrical safety and EMC standards.
- Reliable sourcing of components to avoid supply chain interruptions.
- Efficient inventory management and production planning.

### 9.2 Selling Price Determination

The preliminary manufacturing cost of one prototype unit is estimated to be LKR 33,223. During volume production, the manufacturing cost is expected to decrease due to bulk purchasing, optimized production processes, and automated PCB assembly. However, the final selling price should also include expenses related to product assembly, testing, calibration, packaging, transportation, marketing, warranty services, distributor margins, and company profit.

Considering these factors and the advanced features provided by the Smart Power Quality Analyzer, the proposed selling price is:

Selling Price = USD 300 ≈ LKR 90,000 | (1)

This pricing is justified by the device’s real-time power quality analysis, TFT graphical display, Wi-Fi connectivity, industrial-grade measurement capability, and long-term technical support.

### 9.3 Marketing, Sales and Beyond

The product will be promoted through technical demonstrations, engineering exhibitions, educational institutions, industrial partnerships, and online platforms. Customer support will include firmware updates, calibration services, warranty support, and technical assistance to ensure reliable long-term operation and customer satisfaction.

### 10 Project Budget with Bill of Quantities

Table 5: Preliminary bill of quantities

No. | Item | Quantity | Unit Cost (LKR)

Total Cost
(LKR)
1 | Electronic components used in one analyzer, including pas- sive components
1 set | 12,773 | 12,773
2 | TFT display module | 1 | 6,000 | 6,000
3 | Connectors, terminals, and in- terconnecting cables | 1 set | 2,000 | 2,000
4 | Product enclosure | 1 | 3,000 | 3,000
5 | Hi-Link | isolated | AC–DC
| power-supply module | 1 | 1,450 | 1,450
6 | PCB manufacturing | 1 set | 8,000 | 8,000
Estimated Total Project Cost | 33,223

The estimated total project cost is calculated as

Total Project Cost = 12, 773 + 6, 000 + 2, 000 + 3, 000

+ 1, 450 + 8, 000

= | LKR 33, 223 | .

(2)

This estimate does not include shipping charges, customs duties, soldering expenses, testing equipment, or the cost of replacing damaged components during development.

### 11 Task Allocation

### 11.1 Individual Contributions

11.1.1 230045X - ANTHONY C.S.B.

Power supply and ESP32 circuit designing and component selection, PCB structure and module placement designing, Altium Designing, PCB component placement and PCB assembly, Soldering, ESP32 firmware development, LCD Display programming, PCB Testing, Hardware Assembly

11.1.2 230697V - WEERASINGHE J.A.H.R.

ADC and STM32 Circuit designing and component selection, Schematic design, Altium Designing, PCB component placement and PCB assembly, Soldering, STM32 firmware development, Software debugging, PCB Testing, Hardware Assembly

11.1.3 230100M - CHANDRAKUMARA H.A.D.C.

Component selection, Analog Signal Processing Circuit designing, Signal Acquisition circuit Design, Schematic design, Solidworks enclosure designing, PCB testing and PCB Assembly

11.1.4 230229P - HANSINDU M.M.A.D.

Power supply circuit Designing, Schematic designing, Altium designing, PCB Design Optimization, PCB testing and PCB Assembly, Component Selection

11.1.5 230477X - PERERA H.A.J.I.

Current and Voltage Sensing circuit Design, Enclosure, Web interface Design, Database integration for Data, Firmware modification and Debugging, Hardware and Software testing, LCD display code finalization, Documentation

References

[1] IEEE, IEEE Recommended Practice for Monitoring Electric Power Quality, IEEE Standard 1159.
[2] International Electrotechnical Commission, IEC 61000 Electromagnetic Compatibility Standards.
[3] STMicroelectronics, STM32 Microcontroller Datasheet and Reference Manual.
[4] Espressif Systems, ESP32-S3 Series Datasheet.
[5] Google, Firebase Realtime Database Documentation.

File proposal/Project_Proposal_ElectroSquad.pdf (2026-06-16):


Department of Electronic & Telecommunication Engineering University of Moratuwa
Sri Lanka.

## Project Proposal Smart Power Quality Analyzer

## EN2160 - Electronic Design Realization

Group Name :- ElectroSquad

Anthony C.S.B. | : 230045X
Chandrakumara H.A.D.C. | : 230100M
Hansindu M.M.A.D. | : 230229P
Perera H.A.J.I. | : 230477X
Weerasinghe J.A.H.R. | : 230697V

Date : 12-03-2026

Smart Power Quality Analyzer - Project Proposal | ElectroSquad

Smart Power Quality Analyzer - Project Proposal

### 1 Problem Identification and Justification

Power quality disturbances, such as voltage fluctuations, harmonic distortion, and poor power factor, are common in electrical grids, particularly in developing countries like Sri Lanka. These disturbances can cause equipment malfunction, reduced efficiency, and increased maintenance costs in industrial and institutional settings.
Evidence of this problem is seen in frequent downtime of manufacturing equipment and sensitive electronic devices in laboratories and hospitals due to voltage sags and transients. Small and medium enterprises (SMEs) and educational institutions often lack access to continuous power quality monitoring solutions because commercial analyzers cost between LKR 350,000–1,750,000 per unit.
Although commercial analyzers exist, they are expensive and complex, leaving a gap for a low-cost, locally deployable solution.

### 2 Existing Solutions and Differentiation

Existing power quality analyzers are high-accuracy industrial instruments. Their limitations for widespread adoption include:

- High unit cost (LKR 350,000–1,750,000)
- Complexity in setup and configuration
- Limited real-time remote monitoring options

The Smart Power Quality Analyzer differentiates itself by:

- Significantly lower unit cost (approx. LKR 15,000–25,000) using low-cost microcontrollers and sensors
- Compact, modular PCB-based design with locally sourced components
- Optional cloud-based monitoring with subscription model for remote access and analytics
- Continuous real-time monitoring with local display

2

Smart Power Quality Analyzer - Project Proposal | ElectroSquad

### 3 Proposed Solution and Technical Implementation

The proposed system is a microcontroller-based embedded device designed for continuous monitoring of power quality parameters.

### 3.1 Technical Overview

- Microcontroller: ESP32 for ADC, signal processing, and Wi-Fi connectivity
- Voltage Sensor: ZMPT101B AC voltage transformer module
- Current Sensor: SCT-013 split-core current transformer
- Signal Processing: RMS voltage/current, real/apparent power, power factor, FFTbased harmonic analysis, Total Harmonic Distortion (THD)
- User Interface: OLED or 16x2 LCD display for real-time measurements
- Data Logging: MicroSD card for offline storage; optional cloud integration
- Power Supply: Isolated AC-DC or buck converter module

The device samples voltage and current signals via conditioned ADC inputs, calculates power parameters in real time, and performs FFT to identify harmonic content. Abnormal conditions like voltage sags or high harmonics trigger alerts both locally and via the cloud.

### 3.2 PCB and Component Considerations

Design follows EDR best practices:

- Two-layer PCB layout with careful separation of analog and digital signals
- Component selection based on voltage/current ratings, tolerance, and temperature stability
- Decoupling and filtering for ADC inputs to minimize noise
- Enclosure designed for electrical isolation, durability, and user safety
- Connectors and terminals chosen for secure connections and ease of maintenance

Potential failure modes, including overvoltage, sensor drift, and thermal stress, are mitigated through protective circuitry, calibration, and PCB layout optimization.

3

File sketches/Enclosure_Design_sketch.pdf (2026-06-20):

Top View; Front View

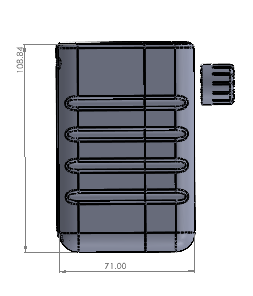
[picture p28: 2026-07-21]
sketches/Side.png

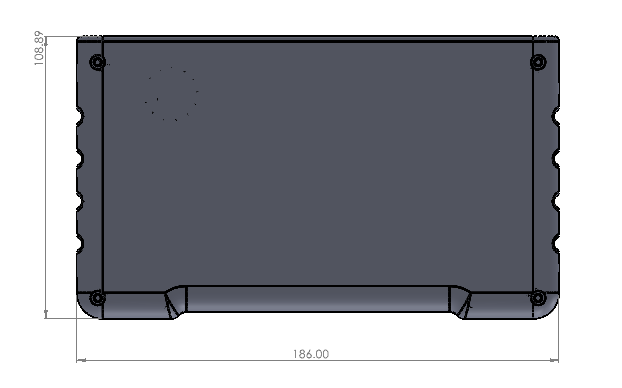
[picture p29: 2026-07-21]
sketches/Back.png

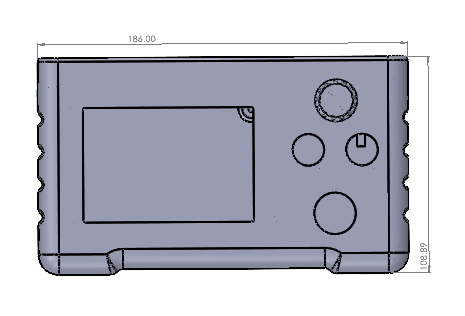
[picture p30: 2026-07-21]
sketches/front.png

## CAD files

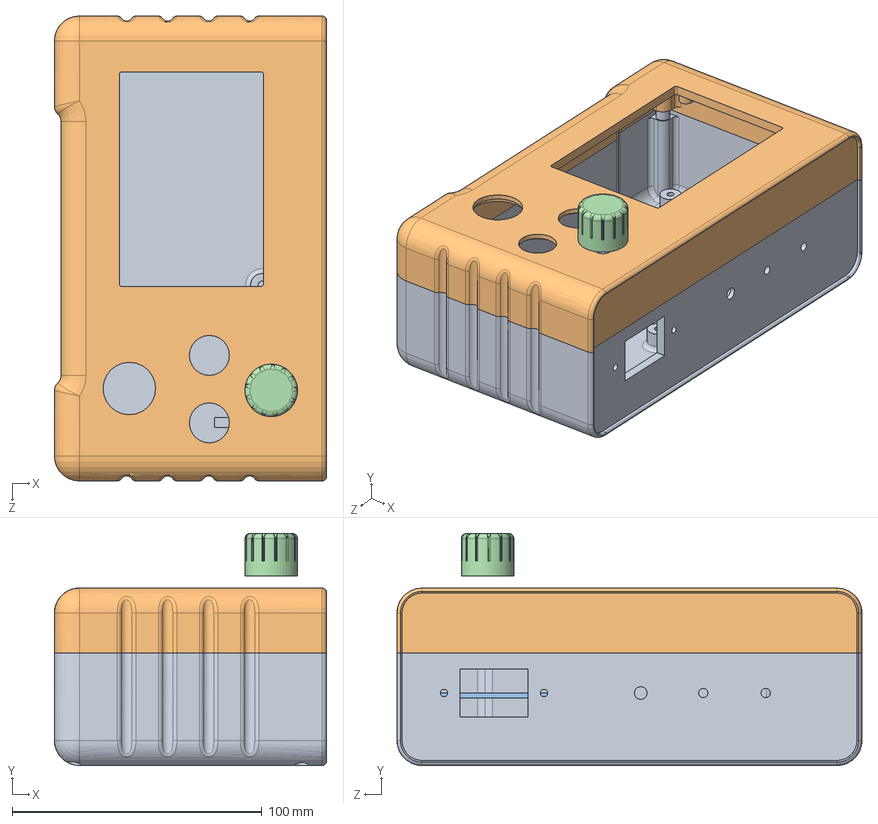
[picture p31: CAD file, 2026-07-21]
design files/solidworks/Assembly.SLDASM
108.9 x 92.8 x 186.0 mm
Lower_Enclosure
Upper_Enclosure
Strip
Knob

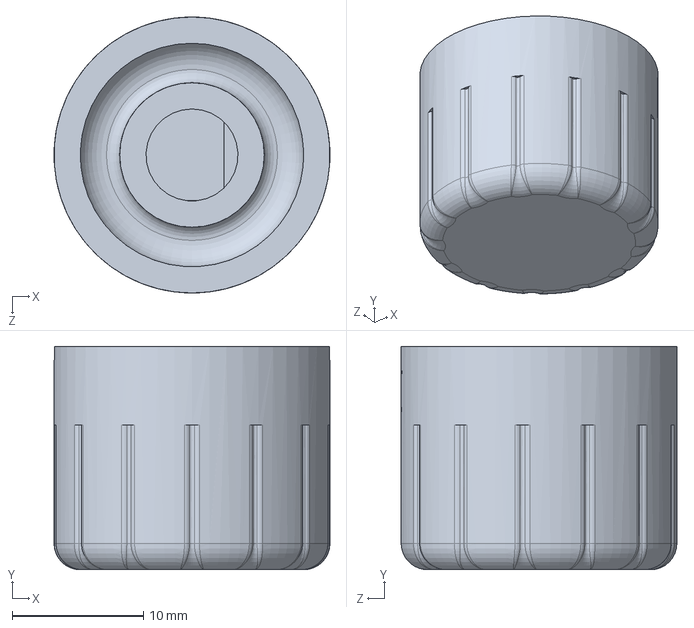
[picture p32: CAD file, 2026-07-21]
design files/solidworks/Knob.SLDPRT
21.0 x 17.0 x 21.0 mm

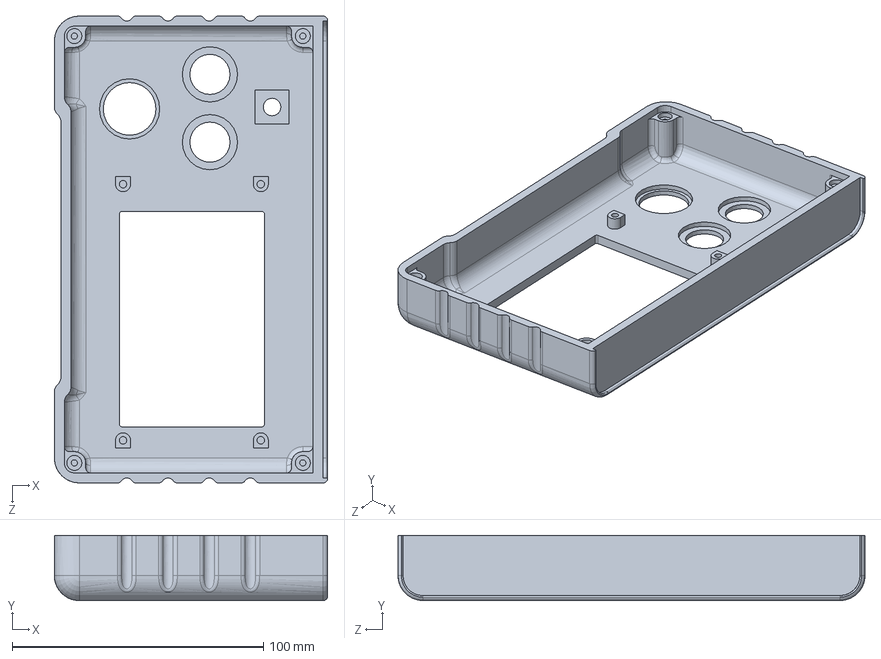
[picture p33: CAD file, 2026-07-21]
design files/solidworks/Upper_Enclosure.SLDPRT
108.9 x 26.0 x 186.0 mm

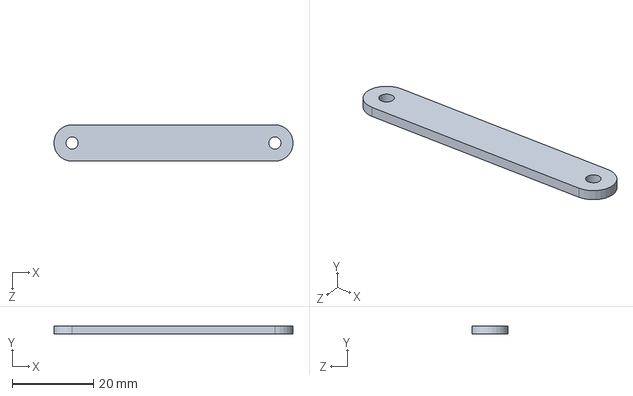
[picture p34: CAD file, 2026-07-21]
design files/solidworks/Strip.SLDPRT
58.9 x 2.00 x 9.00 mm

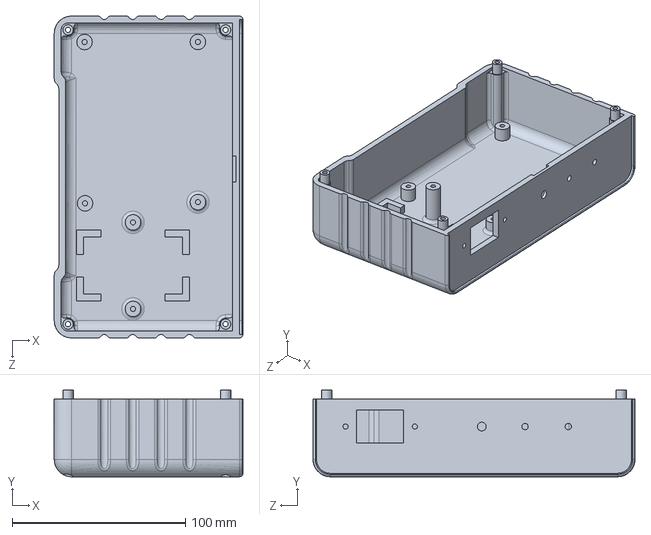
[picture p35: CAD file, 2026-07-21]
design files/solidworks/Lower_Enclosure.SLDPRT
108.9 x 50.0 x 186.0 mm

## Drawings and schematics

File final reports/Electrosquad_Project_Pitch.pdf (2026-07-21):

# Smart Power Quality Analyzer

# Low-cost real-time monitoring for safer and efficient electrical systems

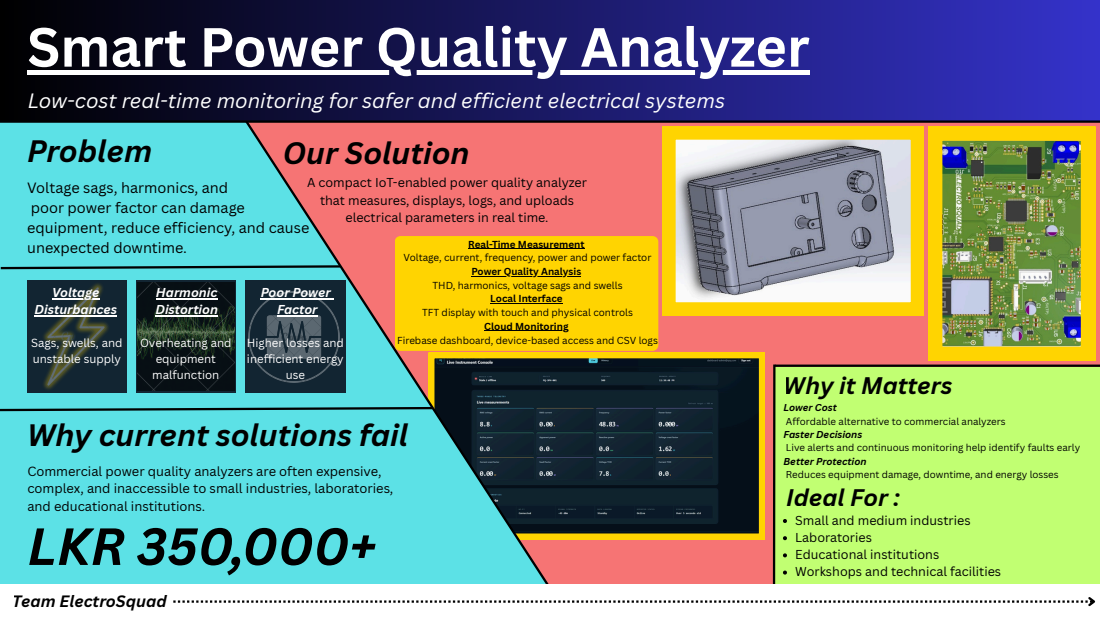
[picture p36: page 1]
unexpected downtime.; Voltage Disturbances; Harmonic Distortion; Poor Power Factor; Overheating and equipment malfunction; Our Solution

Problem Voltage sags, harmonics, and poor power factor can damage equipment, reduce efficiency, and cause | that measures, displays, logs, and uploads electrical parameters in real time.

A compact IoT-enabled power quality analyzer

Real-Time Measurement Voltage, current, frequency, power and power factor Power Quality Analysis THD, harmonics, voltage sags and swells Local Interface TFT display with touch and physical controls Cloud Monitoring Firebase dashboard, device-based access and CSV logs

Sags, swells, and
unstable supply
Why current solutions fail

Higher losses and
inefficient energy
use

Why it Matters

Lower Cost
Affordable alternative to commercial analyzers
Faster Decisions
Live alerts and continuous monitoring help identify faults early
Better Protection
Reduces equipment damage, downtime, and energy losses
Ideal For :

Commercial power quality analyzers are often expensive,
complex, and inaccessible to small industries, laboratories,
and educational institutions.

LKR 350,000+

Small and medium industries
Laboratories
Educational institutions
Workshops and technical facilities

Team ElectroSquad

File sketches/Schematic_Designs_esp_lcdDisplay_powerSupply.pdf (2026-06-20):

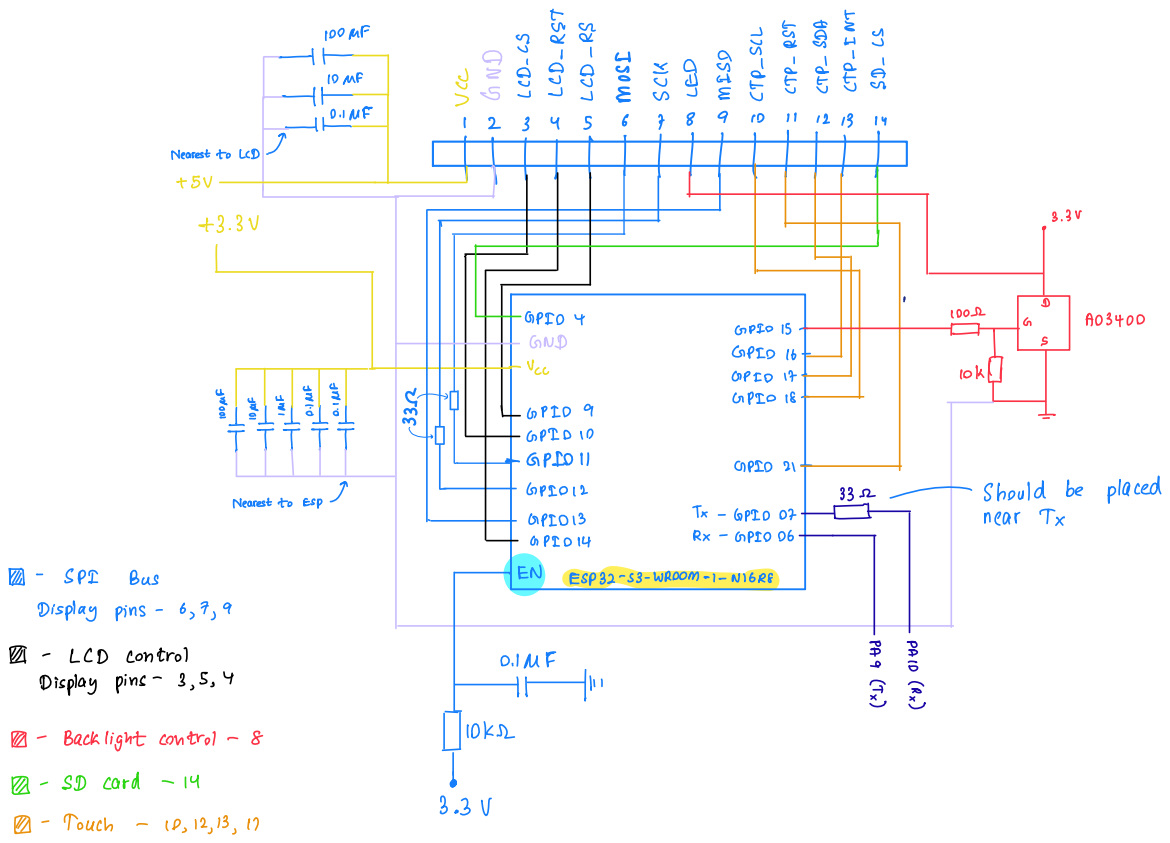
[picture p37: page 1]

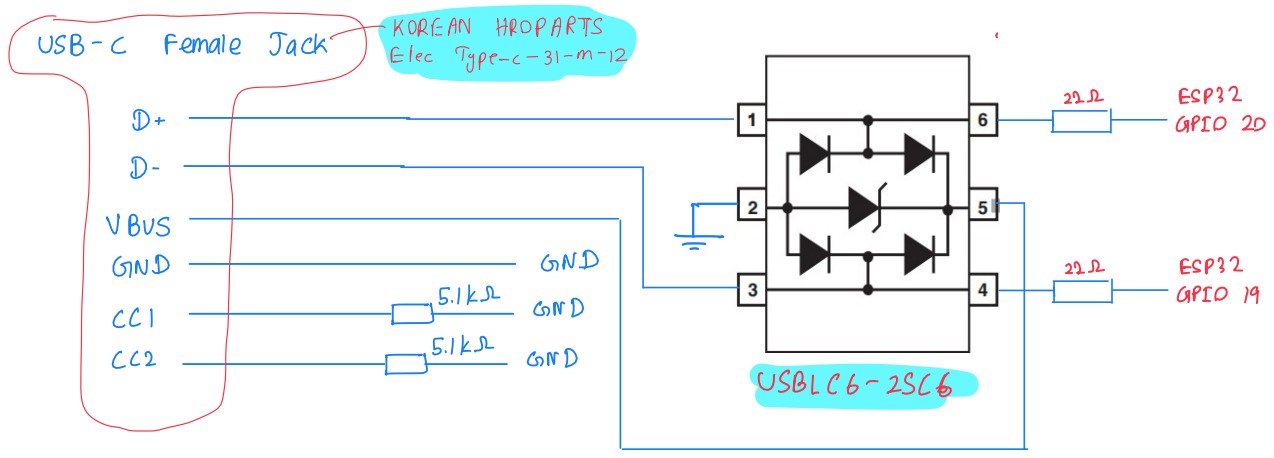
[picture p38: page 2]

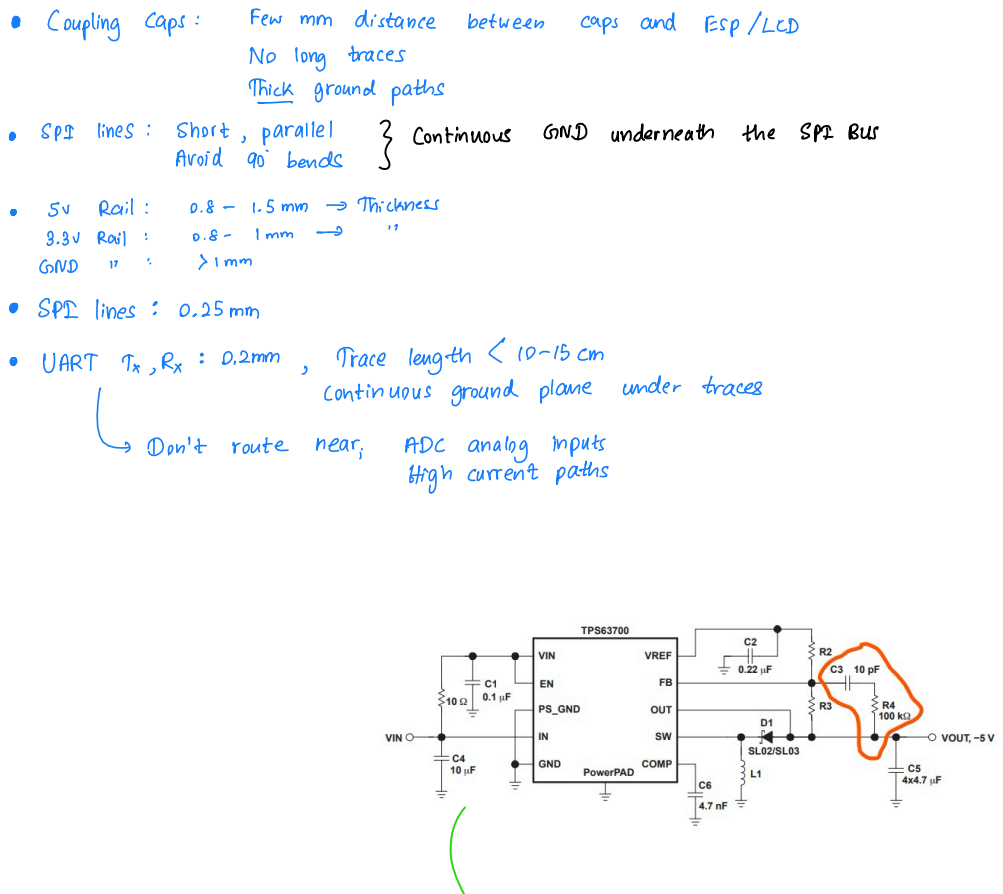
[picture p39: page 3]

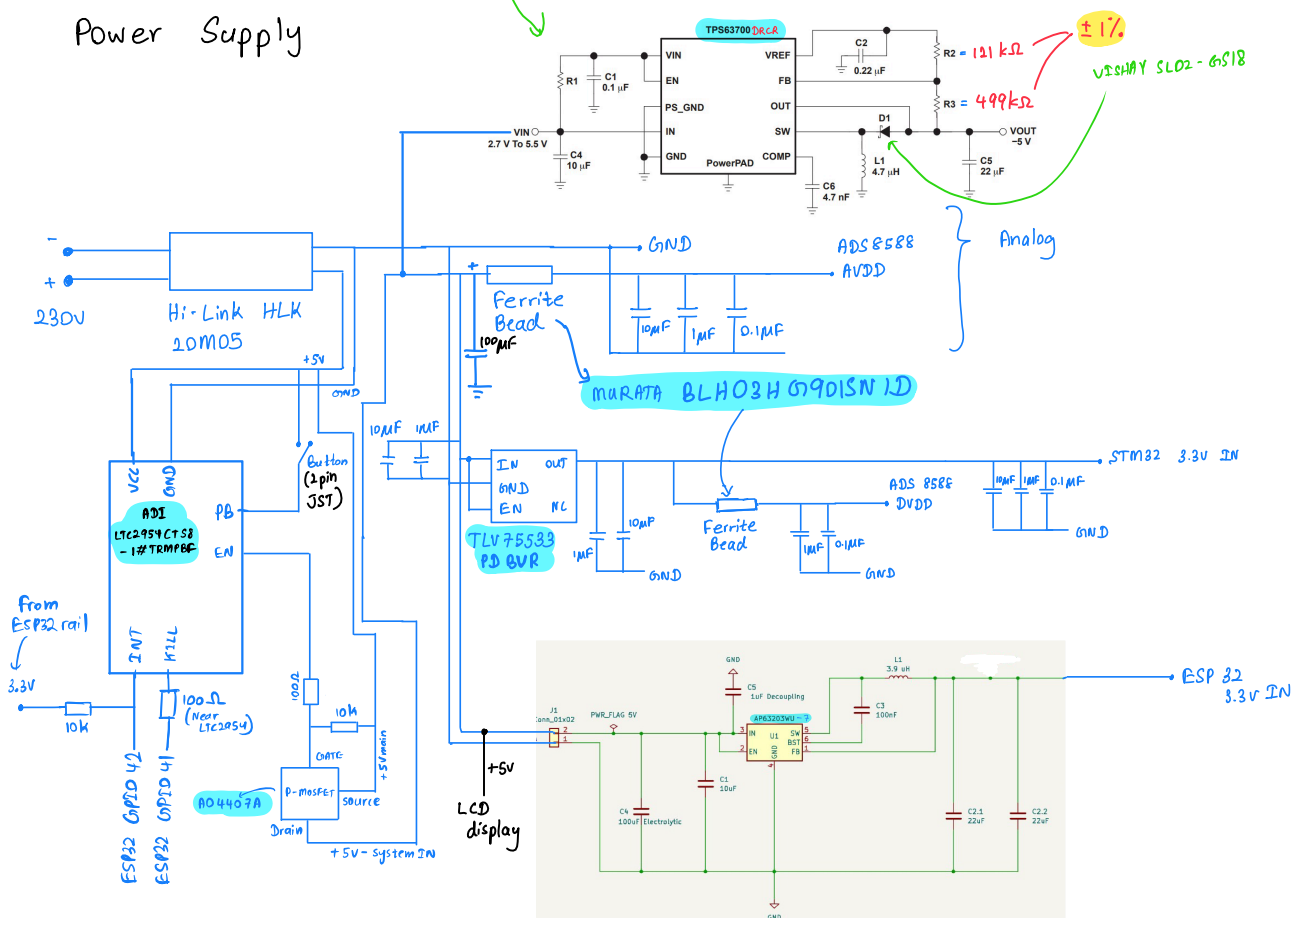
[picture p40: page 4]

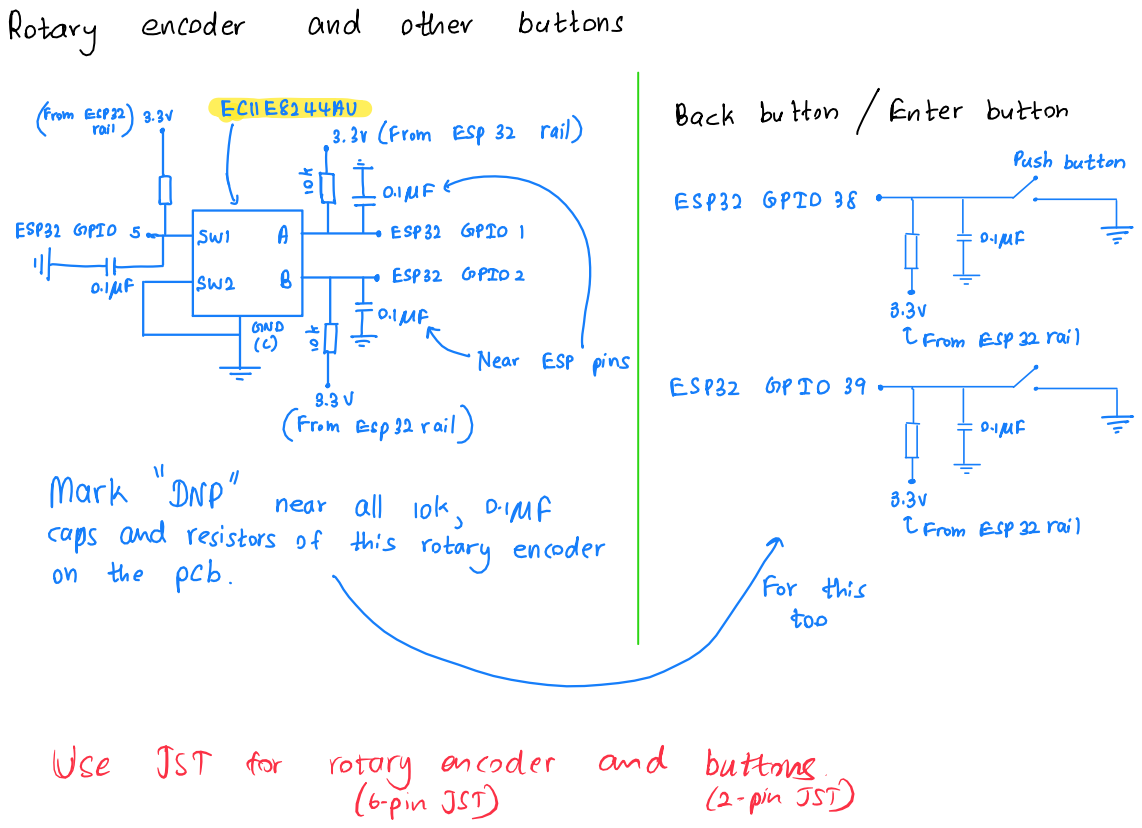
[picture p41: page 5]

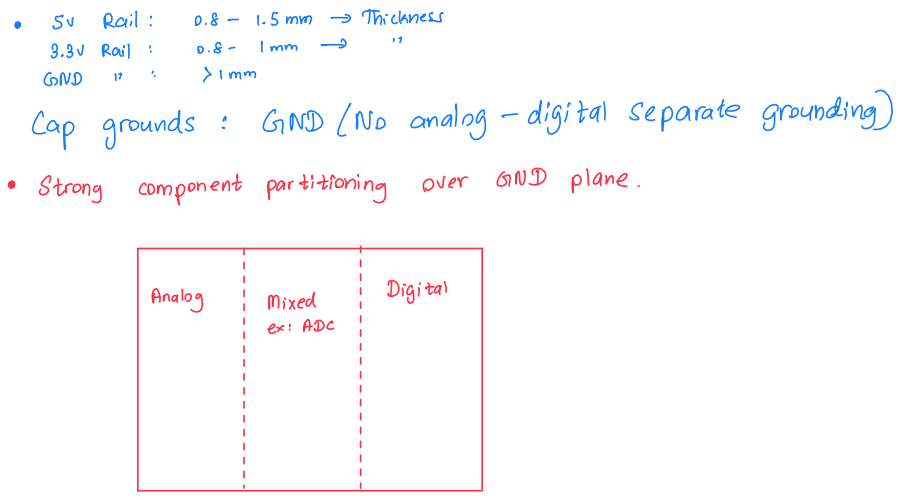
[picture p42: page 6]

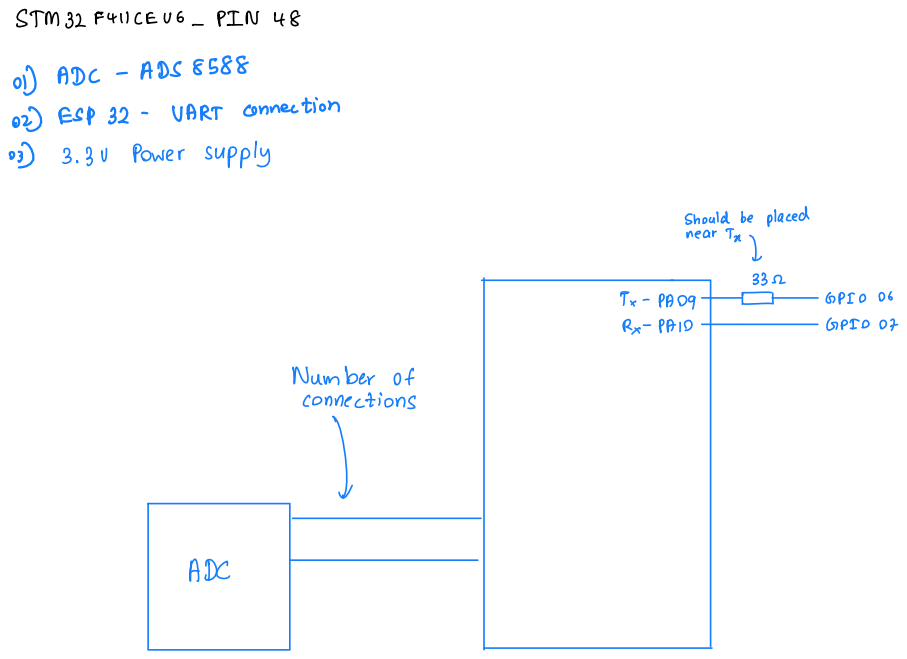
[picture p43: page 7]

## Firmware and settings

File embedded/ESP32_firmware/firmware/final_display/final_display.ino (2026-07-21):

#include "TestConsoleConfig.h"
#include "WiFiManager.h"
#include <TFT_eSPI.h> 
#include <SPI.h>
#include "touch.h"
#include <math.h> // Needed for the sin() function
#include <WiFi.h>
#include "FirebaseBridge.h"
#include "SessionLogger.h"
#include "SessionStorage.h"
#include "SessionUiController.h"
#include "FlashRecordCodec.h"
#include "WallClockService.h"
#include "ProvisioningConfig.h"
#include "AcquisitionDiagnostics.h"
#include "AcquisitionPolicy.h"
#include <driver/gpio.h>
#include <esp_heap_caps.h>
#include <esp_timer.h>
#include <string.h>

// --- UART Pin Definitions for STM32 ---
#define STM_RX_PIN 6 // Connect to STM32 TX
#define STM_TX_PIN 7 // Connect to STM32 RX

// --- Hardware Control Pins ---
#define ENC_A 1
#define ENC_B 2
#define ENC_SW 5
#define BTN_SEL 38
#define BTN_BACK 39

// Board-level safety output. Software can enforce this only after application
// startup; use an external pull-down when GPIO15 must also be LOW at power-up.
constexpr gpio_num_t HARDWARE_HOLD_LOW_GPIO = GPIO_NUM_15;
static_assert(static_cast<int>(HARDWARE_HOLD_LOW_GPIO) == 15,
              "The board hold-low output must remain GPIO15");
static_assert(static_cast<int>(HARDWARE_HOLD_LOW_GPIO) != STM_RX_PIN &&
                  static_cast<int>(HARDWARE_HOLD_LOW_GPIO) != STM_TX_PIN &&
                  static_cast<int>(HARDWARE_HOLD_LOW_GPIO) != ENC_A &&
                  static_cast<int>(HARDWARE_HOLD_LOW_GPIO) != ENC_B &&
                  static_cast<int>(HARDWARE_HOLD_LOW_GPIO) != ENC_SW &&
                  static_cast<int>(HARDWARE_HOLD_LOW_GPIO) != BTN_SEL &&
                  static_cast<int>(HARDWARE_HOLD_LOW_GPIO) != BTN_BACK,
              "GPIO15 must not conflict with UART or user-input pins");
static_assert(static_cast<int>(HARDWARE_HOLD_LOW_GPIO) != TOUCH_FT6336_SCL &&
                  static_cast<int>(HARDWARE_HOLD_LOW_GPIO) !=
                      TOUCH_FT6336_SDA &&
                  static_cast<int>(HARDWARE_HOLD_LOW_GPIO) !=
                      TOUCH_FT6336_INT &&
                  static_cast<int>(HARDWARE_HOLD_LOW_GPIO) !=
                      TOUCH_FT6336_RST,
              "GPIO15 must not conflict with touch-controller pins");
#if defined(TFT_MOSI) && defined(TFT_MISO) && defined(TFT_SCLK) && \
    defined(TFT_CS) && defined(TFT_DC) && defined(TFT_RST)
static_assert(static_cast<int>(HARDWARE_HOLD_LOW_GPIO) != TFT_MOSI &&
                  static_cast<int>(HARDWARE_HOLD_LOW_GPIO) != TFT_MISO &&
                  static_cast<int>(HARDWARE_HOLD_LOW_GPIO) != TFT_SCLK &&
                  static_cast<int>(HARDWARE_HOLD_LOW_GPIO) != TFT_CS &&
                  static_cast<int>(HARDWARE_HOLD_LOW_GPIO) != TFT_DC &&
                  static_cast<int>(HARDWARE_HOLD_LOW_GPIO) != TFT_RST,
              "GPIO15 must not conflict with the active TFT pin map");
#endif

// --- UART & Packet Definitions ---
#define SAMPLES 1024
#define HARMONICS 25

typedef struct __attribute__((packed)) {
    uint32_t start_byte;
    uint32_t seq;
    int16_t  voltage[SAMPLES];
    int16_t  current[SAMPLES];
    float    v_rms, i_rms;
    float    frequency;
    float    power_factor;
    float    active_power, apparent_power, reactive_power;
    float    crest_factor_v, crest_factor_i;
    float    swell_factor;
    float    thd_v, thd_i;
    float    harmonics_v[HARMONICS];
    float    harmonics_i[HARMONICS];
    uint16_t checksum;
} WaveformPacket_t;

static_assert(sizeof(WaveformPacket_t) == SESSION_PACKET_BYTES,
              "WaveformPacket_t must remain exactly 4354 bytes");

WaveformPacket_t pkt;
FirebaseBridge firebaseBridge;
SessionLogger sessionLogger;
SessionStorage sessionStorage;
WallClockService wallClockService;
SessionUiController sessionUiController;
bool gpio15HoldLowConfigured = false;

// --- Timing Globals ---
uint32_t lastUIUpdate = 0;
const uint32_t UI_REFRESH_RATE = 500; 
const uint32_t LOG_STORAGE_REFRESH_RATE = 300;
const uint32_t FOOTER_CLOCK_REFRESH_RATE = 1000;

uint32_t lastGraphUpdate = 0;
const uint32_t GRAPH_REFRESH_RATE = 100; 

char systemFooterClockText[64] =
    "Sys Clock:  ---- / -- / --   --:--";
uint32_t lastFooterClockRefreshMs = 0U;
bool footerClockCacheInitialized = false;
bool footerClockHasValidTime = false;

#if SESSION_STORAGE_TEST_CONSOLE || SESSION_SYNC_TEST_CONSOLE
bool uartRxBufferInternal = false;
uint32_t uartRxBufferConfiguredBytes = 0U;
uint32_t uartRxInternalHeapDeltaBytes = 0U;
#endif

// --- UI Globals ---
TFT_eSPI my_lcd = TFT_eSPI();

// --- Colors ---
#define BLACK   0x0000
#define BLUE    0x001F
#define RED     0xF800
#define GREEN   0x07E0
#define YELLOW  0xFFE0
#define ORANGE  0xFDA0
#define MAGENTA 0xF81F
#define WHITE   0xFFFF
#define GRAY    0x8410
#define DARK_BG 0x18E3 
#define IND_BG      0x0000 
#define IND_TEXT    0xFFFF 
#define IND_ACCENT  0x07FF 
#define IND_WARN    0xFD20 

// --- Screen States ---
enum ScreenState {
  SPLASH_SCREEN,
  SETUP_DATETIME_SCREEN,  // Reserved legacy value; no runtime route enters it.
  HOME_SCREEN,
  MENU_SCREEN,
  MEASUREMENTS_SCREEN,
  GRAPHS_MENU,
  TIME_DOMAIN_MENU,
  FREQUENCY_DOMAIN_MENU,
  GRAPH_VOLTAGE,
  GRAPH_CURRENT,
  LOG_SCREEN,
  SETTINGS_SCREEN,
  WIFI_MENU_SCREEN,
  ABOUT_SCREEN
};

ScreenState currentState = SPLASH_SCREEN;
int currentMeasurementPage = 1; 
bool isLogging = false; 
bool isWifiConnected = false;
bool isTimeDomain = true; 
bool screenNeedsUpdate = true; 

// Settings Variables
int logIntervals[] = {1, 5, 10, 60}; 
int currentLogIntervalIdx = 0; 
int encoderSensitivity = 4; // Standard detent ticks per movement

// --- Navigation Globals ---
struct FocusRect {
    int16_t x, y, w, h;
};
FocusRect currentFocusElements[10];
int currentFocusCount = 0;
int currentFocusIndex = 0;
int lastFocusIndex = -1;
volatile int encoderDelta = 0;

// --- Forward Declarations ---
void updateHomeScreenData();
void updateMeasurementsScreenData();
void updateStaticGraphRealTime(bool isVoltage);
void updateFFTGraphRealTime(bool isVoltage);
void defineFocusElements();
void drawFocus();
void drawSystemFooter();
bool refreshSystemFooterClockCache(bool force);
void serviceSystemFooterClock();
void drawStartupConnectionStatus(const char* message, uint16_t color);
void drawStartupProvisioningInfo();
void updateLogStorageIndicators(const SessionUiSnapshot& ui, bool force);
void updateLogStatusIndicator(const SessionUiSnapshot& ui, bool force);
void handleInteraction(int16_t x, int16_t y);
bool startLoggingSession();
bool requestLoggingStop();
bool requestSessionSynchronization();
SessionUiClearAction requestRetainedSessionClear();
void synchronizeLoggingState();
bool configureGpio15HeldLow();
const char* sessionUiMessageText(SessionUiMessage message);
uint16_t sessionUiMessageColor(SessionUiMessage message);

#if SESSION_STORAGE_TEST_CONSOLE || SESSION_SYNC_TEST_CONSOLE
void processSessionStorageTestConsole();
void printSessionStorageTestStatus();
void printSessionStorageTestHelp();
void reportSessionStorageTestStateChange();
#if SESSION_SYNC_TEST_CONSOLE
void printSessionSyncTestStatus();
#endif
#endif

// --- Hardware Interrupts & Inputs ---
void encoderISR() {
    static uint8_t old_AB = 0;
    static const int8_t enc_states[] = {0, -1, 1, 0, 1, 0, 0, -1, -1, 0, 0, 1, 0, 1, -1, 0};
    
    uint8_t A = digitalRead(ENC_A);
    uint8_t B = digitalRead(ENC_B);
    
    old_AB <<= 2;
    old_AB |= ((A << 1) | B);
    encoderDelta += enc_states[(old_AB & 0x0f)];
}

bool isSelectPressed() {
    static unsigned long lastPress = 0;
    bool stateSW = digitalRead(ENC_SW);
    bool stateBtn = digitalRead(BTN_SEL);
    if ((stateSW == LOW || stateBtn == LOW) && (millis() - lastPress > 250)) {
        lastPress = millis();
        return true;
    }
    return false;
}

bool isBackPressed() {
    static unsigned long lastPress = 0;
    if (digitalRead(BTN_BACK) == LOW && (millis() - lastPress > 250)) {
        lastPress = millis();
        return true;
    }
    return false;
}

#if SESSION_STORAGE_TEST_CONSOLE || SESSION_SYNC_TEST_CONSOLE
void handleStm32UartReceiveError(hardwareSerial_error_t error) {
    if (error == UART_FIFO_OVF_ERROR) {
        AcquisitionDiagnostics::noteUartFifoOverflow();
    } else if (error == UART_BUFFER_FULL_ERROR) {
        AcquisitionDiagnostics::noteUartRingBufferOverflow();
    }
}
#endif

bool configureGpio15HeldLow() {
    // Load the LOW output latch before enabling the driver to minimize any
    // application-controlled HIGH transient, then assert LOW once more.
    const esp_err_t preloadResult =
        gpio_set_level(HARDWARE_HOLD_LOW_GPIO, 0U);
    const esp_err_t directionResult =
        gpio_set_direction(HARDWARE_HOLD_LOW_GPIO, GPIO_MODE_OUTPUT);
    const esp_err_t finalLevelResult =
        gpio_set_level(HARDWARE_HOLD_LOW_GPIO, 0U);
    return preloadResult == ESP_OK && directionResult == ESP_OK &&
           finalLevelResult == ESP_OK;
}

bool startLoggingSession() {
    const SessionUiRequestDecision decision = sessionUiController.requestStart(
        static_cast<uint32_t>(logIntervals[currentLogIntervalIdx]));
    screenNeedsUpdate = true;
    return decision == SessionUiRequestDecision::Allowed;
}

bool requestLoggingStop() {
    const SessionUiRequestDecision decision =
        sessionUiController.requestStop();
    const bool accepted = decision == SessionUiRequestDecision::Allowed ||
                          decision == SessionUiRequestDecision::Idempotent;
    if (accepted) {
        isLogging = false;
    }
    screenNeedsUpdate = true;
    return accepted;
}

bool requestSessionSynchronization() {
    const SessionUiRequestDecision decision =
        sessionUiController.requestSync();
    screenNeedsUpdate = true;
    return decision == SessionUiRequestDecision::Allowed ||
           decision == SessionUiRequestDecision::Idempotent ||
           decision == SessionUiRequestDecision::AlreadySynchronized;
}

SessionUiClearAction requestRetainedSessionClear() {
    const SessionUiClearAction action =
        sessionUiController.requestClear(millis());
    screenNeedsUpdate = true;
    return action;
}

void synchronizeLoggingState() {
    static bool snapshotInitialized = false;
    static SessionUiSnapshot previous{};
    sessionUiController.service(millis(), currentState == LOG_SCREEN);
    const SessionUiSnapshot current = sessionUiController.getSnapshot();
    const bool loggerActive =
        current.loggerState == SessionLoggerState::Active;
    if (isLogging != loggerActive) {
        isLogging = loggerActive;
    }

    const bool changed = !snapshotInitialized ||
        previous.message != current.message ||
        previous.loggerState != current.loggerState ||
        previous.persistentState != current.persistentState ||
        previous.localSynchronizationState !=
            current.localSynchronizationState ||
        previous.storageAvailable != current.storageAvailable ||
        previous.recoveryBlocked != current.recoveryBlocked ||
        previous.uploadedRecords != current.uploadedRecords ||
        previous.currentChunk != current.currentChunk ||
        previous.totalChunks != current.totalChunks ||
        previous.clearConfirmationArmed != current.clearConfirmationArmed ||
        previous.clearInProgress != current.clearInProgress ||
        previous.clearCompleted != current.clearCompleted;
    previous = current;
    snapshotInitialized = true;
    if (changed && currentState == LOG_SCREEN) {
        screenNeedsUpdate = true;
    }
    const bool storageEstimatePhase =
        current.loggerState == SessionLoggerState::Starting ||
        current.loggerState == SessionLoggerState::PreparingStorage ||
        current.loggerState == SessionLoggerState::Active ||
        current.loggerState == SessionLoggerState::Stopping ||
        current.loggerState == SessionLoggerState::Finalizing;
    if (currentState == LOG_SCREEN && !screenNeedsUpdate &&
        storageEstimatePhase) {
        updateLogStorageIndicators(current, false);
        updateLogStatusIndicator(current, false);
    }
}

const char* sessionUiMessageText(SessionUiMessage message) {
    switch (message) {
        case SessionUiMessage::Standby: return "Standby";
        case SessionUiMessage::Starting: return "Starting";
        case SessionUiMessage::PreparingStorage: return "Preparing storage...";
        case SessionUiMessage::Logging: return "Logging";
        case SessionUiMessage::Stopping: return "Stopping";
        case SessionUiMessage::Draining: return "Draining";
        case SessionUiMessage::Finalizing: return "Finalizing";
        case SessionUiMessage::Finalized: return "Finalized";
        case SessionUiMessage::StorageFull: return "Storage full";
        case SessionUiMessage::Recovered: return "Recovered";
        case SessionUiMessage::StartFailed: return "Start failed";
        case SessionUiMessage::StopFailed: return "Stop failed";
        case SessionUiMessage::WaitingForWifi: return "Waiting for Wi-Fi";
        case SessionUiMessage::Uploading: return "Uploading";
        case SessionUiMessage::Verifying: return "Verifying";
        case SessionUiMessage::Synced: return "Synced";
        case SessionUiMessage::SyncFailed: return "Sync failed";
        case SessionUiMessage::ClearConfirmation: return "Press Clear All again";
        case SessionUiMessage::ClearUnsyncedConfirmation: return "Unsynced data will be deleted";
        case SessionUiMessage::Clearing: return "Clearing...";
        case SessionUiMessage::StorageCleared: return "Storage cleared";
        case SessionUiMessage::ClearFailed: return "Clear failed";
        case SessionUiMessage::StorageError: return "Storage error";
        default: return "Standby";
    }
}

uint16_t sessionUiMessageColor(SessionUiMessage message) {
    switch (message) {
        case SessionUiMessage::Logging:
        case SessionUiMessage::Finalized:
        case SessionUiMessage::Synced:
        case SessionUiMessage::StorageCleared:
            return TFT_GREEN;
        case SessionUiMessage::Starting:
        case SessionUiMessage::PreparingStorage:
        case SessionUiMessage::Stopping:
        case SessionUiMessage::Draining:
        case SessionUiMessage::Finalizing:
        case SessionUiMessage::Recovered:
        case SessionUiMessage::WaitingForWifi:
        case SessionUiMessage::Verifying:
        case SessionUiMessage::ClearConfirmation:
        case SessionUiMessage::ClearUnsyncedConfirmation:
        case SessionUiMessage::Clearing:
            return TFT_ORANGE;
        case SessionUiMessage::Uploading:
            return TFT_CYAN;
        case SessionUiMessage::StartFailed:
        case SessionUiMessage::StopFailed:
        case SessionUiMessage::SyncFailed:
        case SessionUiMessage::ClearFailed:
        case SessionUiMessage::StorageError:
        case SessionUiMessage::StorageFull:
            return TFT_RED;
        case SessionUiMessage::Standby:
        default:
            return TFT_DARKGREY;
    }
}

#if SESSION_STORAGE_TEST_CONSOLE || SESSION_SYNC_TEST_CONSOLE
const char* sessionLoggerStateText(SessionLoggerState state) {
    switch (state) {
        case SessionLoggerState::Disabled: return "Disabled";
        case SessionLoggerState::Idle: return "Idle";
        case SessionLoggerState::Starting: return "Starting";
        case SessionLoggerState::PreparingStorage: return "PreparingStorage";
        case SessionLoggerState::Active: return "Active";
        case SessionLoggerState::Stopping: return "Stopping";
        case SessionLoggerState::Finalizing: return "Finalizing";
        case SessionLoggerState::Finalized: return "Finalized";
        case SessionLoggerState::RecoveredIncomplete: return "RecoveredIncomplete";
        case SessionLoggerState::Clearing: return "Clearing";
        case SessionLoggerState::Rescanning: return "Rescanning";
        case SessionLoggerState::ErrorIncomplete: return "ErrorIncomplete";
        case SessionLoggerState::Error: return "Error";
        default: return "Unknown";
    }
}

const char* persistentSessionStateText(PersistentSessionState state) {
    switch (state) {
        case PersistentSessionState::Empty: return "Empty";
        case PersistentSessionState::Active: return "Active";
        case PersistentSessionState::Stopping: return "Stopping";
        case PersistentSessionState::Finalized: return "Finalized";
        case PersistentSessionState::RecoveredIncomplete: return "RecoveredIncomplete";
        case PersistentSessionState::ErrorIncomplete: return "ErrorIncomplete";
        default: return "Unknown";
    }
}

void printSessionStorageTestHelp() {
    Serial.println("Stage 3 storage test console:");
    Serial.println("  1/5/0/6 = select 1/5/10/60-second flush interval");
    Serial.println("  L = start, S = stop and drain, P = status");
    Serial.println("  C = arm retained-session clear, Y = confirm clear");
    Serial.println("  V = validate/re-scan retained storage, H = help");
#if SESSION_SYNC_TEST_CONSOLE
    Serial.println("Stage 4 session sync test console:");
    Serial.println("  U = start/resume upload, X = cancel upload, Q = sync status");
#endif
}

#if SESSION_SYNC_TEST_CONSOLE
bool sessionSyncOperationActive(SessionSyncState state) {
    return state != SessionSyncState::Disabled &&
           state != SessionSyncState::Idle &&
           state != SessionSyncState::Cancelled &&
           state != SessionSyncState::Complete &&
           state != SessionSyncState::Error;
}
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
void loop() {
    // 1. Process Incoming Packets over RX0 & Trigger Graph/Text Updates
    synchronizeLoggingState();
    readUART();
    wallClockService.service();
    serviceSystemFooterClock();
#if SESSION_STORAGE_TEST_CONSOLE || SESSION_SYNC_TEST_CONSOLE
    processSessionStorageTestConsole();
#endif

    // 2. Draw Static Screens
    if (screenNeedsUpdate) {
        screenNeedsUpdate = false; 

        switch (currentState) {
            case SPLASH_SCREEN: drawSplashScreen(); break;
            case HOME_SCREEN: drawHomeScreen(); updateHomeScreenData(); break;
            case MENU_SCREEN: drawMenuScreen(); break;
            case MEASUREMENTS_SCREEN: drawMeasurementsScreen(); updateMeasurementsScreenData(); break;
            case LOG_SCREEN: drawLogScreen(); break;
            case SETTINGS_SCREEN: drawSettingsScreen(); break;
            case WIFI_MENU_SCREEN: drawWifiMenuScreen(); break;
            case ABOUT_SCREEN: drawAboutScreen(); break;
            case GRAPHS_MENU: drawGraphsMenu(); break;
            case TIME_DOMAIN_MENU: drawParameterMenu("Time Domain"); break;
            case FREQUENCY_DOMAIN_MENU: drawParameterMenu("Freq Domain"); break;
            case GRAPH_VOLTAGE: 
                if (isTimeDomain) { drawStaticGraph(true); updateStaticGraphRealTime(true); } 
                else { drawFFTGraph(true); updateFFTGraphRealTime(true); }
                break;
            case GRAPH_CURRENT: 
                if (isTimeDomain) { drawStaticGraph(false); updateStaticGraphRealTime(false); } 
                else { drawFFTGraph(false); updateFFTGraphRealTime(false); }
                break;
        }
        
        // Ensure footer draws on all screens except Splash
        if(currentState != SPLASH_SCREEN) {
            drawSystemFooter();
            defineFocusElements();
            drawFocus();
        }
    }

    // 3. Handle Rotary Encoder Input
    if (abs(encoderDelta) >= encoderSensitivity) {
        // Calculate how many distinct UI ticks occurred based on sensitivity
        int ticks = encoderDelta / encoderSensitivity;
        encoderDelta = encoderDelta % encoderSensitivity; // Keep remainder to stay smooth
        
        if (currentFocusCount > 0) {
            // Normal Navigation behavior
            currentFocusIndex += ticks;
            
            if (currentFocusIndex >= currentFocusCount) currentFocusIndex = currentFocusIndex % currentFocusCount;
            while (currentFocusIndex < 0) currentFocusIndex += currentFocusCount;
            
            drawFocus(); 
        }
    }

    // 4. Handle Hardware Button Input (Select & Back)
    if (isSelectPressed() && currentFocusCount > 0) {
        int16_t simX = currentFocusElements[currentFocusIndex].x + (currentFocusElements[currentFocusIndex].w / 2);
        int16_t simY = currentFocusElements[currentFocusIndex].y + (currentFocusElements[currentFocusIndex].h / 2);
        handleInteraction(simX, simY);
    }
    else if (isBackPressed()) {
        switch(currentState) {
            case MENU_SCREEN: handleInteraction(100, 250); break; 
            case MEASUREMENTS_SCREEN: handleInteraction(70, 275); break;
            case LOG_SCREEN: handleInteraction(80, 270); break;
            case GRAPHS_MENU: handleInteraction(240, 240); break;
            case TIME_DOMAIN_MENU: handleInteraction(240, 240); break;
            case FREQUENCY_DOMAIN_MENU: handleInteraction(240, 240); break;
            case GRAPH_VOLTAGE: handleInteraction(75, 275); break;
            case GRAPH_CURRENT: handleInteraction(75, 275); break;
            case SETTINGS_SCREEN: handleInteraction(70, 275); break;
            case WIFI_MENU_SCREEN: handleInteraction(125, 255); break;
            case ABOUT_SCREEN: handleInteraction(80, 270); break;
            default: break; 
        }
    }

    // 5. Handle Touch Input
    if (touch_touched()) {
        int16_t x = touch_last_x;
        int16_t y = touch_last_y;
        while (touch_touched()) { delay(10); } 
        handleInteraction(x, y);
    }
}

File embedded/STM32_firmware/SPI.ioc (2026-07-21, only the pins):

Mcu.UserName=STM32F411CEUx
PA0-WKUP.Signal=S_TIM2_CH1_ETR
PA1.Signal=GPXTI1
PA11.Signal=USART6_TX
PA12.Signal=USART6_RX
PA2.Signal=GPIO_Output
PA3.Signal=GPIO_Output
PA5.Signal=SPI1_SCK
PA6.Signal=SPI1_MISO
PA7.Signal=SPI1_MOSI

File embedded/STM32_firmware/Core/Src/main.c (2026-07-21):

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
/* Includes ------------------------------------------------------------------*/
#include "main.h"

/* USER CODE BEGIN Includes */
#include "arm_math.h"
#include <string.h>
#include <math.h>
/* USER CODE END Includes */

/* USER CODE BEGIN PTD */
#define SAMPLES 1024
#define HARMONICS 25

// DSP Calibration (Multiplying by inverse is faster than division)
#define V_CALIBRATION_FACTOR (1.0f / 63.9204f)
#define I_CALIBRATION_FACTOR (1.0f / 432.5244f)
#define SAMPLING_FREQ 10000.0f

//static uint32_t tx_start_tick = 0;

typedef struct __attribute__((packed)) {
    uint32_t  start_byte;
    uint32_t  seq;

    int16_t  voltage[SAMPLES];
    int16_t  current[SAMPLES];

    float    v_rms, i_rms;
    float    frequency;
    float    power_factor;
    float    active_power, apparent_power, reactive_power;
    float    crest_factor_v, crest_factor_i;
    float    swell_factor;
    float    thd_v, thd_i;
    float    harmonics_v[HARMONICS];
    float    harmonics_i[HARMONICS];

    uint16_t checksum;
} WaveformPacket_t;   // 4351 bytes total

static WaveformPacket_t pkt;
static volatile uint8_t tx_busy = 0;
/* USER CODE END PTD */

SPI_HandleTypeDef hspi1;
DMA_HandleTypeDef hdma_spi1_rx;
DMA_HandleTypeDef hdma_spi1_tx;

TIM_HandleTypeDef htim2;

UART_HandleTypeDef huart6;
DMA_HandleTypeDef hdma_usart6_tx;

/* USER CODE BEGIN PV */
int16_t dma_rx_buffer[5]; // to store each 100us SPI output of first 5 channel

//For testing Only
int16_t dummy_tx[5] = {0, 0, 0, 0, 0};
volatile uint32_t dma_errors = 0;
volatile HAL_StatusTypeDef last_spi_status = HAL_OK;


int16_t voltage_A[1024];
int16_t current_A[1024];
int16_t voltage_B[1024];
int16_t current_B[1024];

//Parameters for tracking
volatile uint16_t local_sample = 0;
volatile uint8_t fill_half_A = 1;   // 1 = Writing to A arrays, 0 = Writing to B arrays

volatile uint8_t process_half_A = 0;
volatile uint8_t process_half_B = 0;

volatile uint8_t process_buffer_flag = 0;
uint32_t seq_counter = 0;

// DSP Static Arrays (Kept in global RAM to save stack space)
static float32_t v_float[SAMPLES];
static float32_t i_float[SAMPLES];

static float32_t fft_output_v[SAMPLES];
static float32_t magnitudes_v[SAMPLES / 2];

static float32_t fft_output_i[SAMPLES];
static float32_t magnitudes_i[SAMPLES / 2];

/* USER CODE END PV */

void SystemClock_Config(void);
static void MX_GPIO_Init(void);
static void MX_DMA_Init(void);
static void MX_SPI1_Init(void);
static void MX_TIM2_Init(void);
static void MX_USART6_UART_Init(void);
/* USER CODE BEGIN PFP */


static uint16_t compute_checksum(const uint8_t *data, size_t len)
{
    uint16_t sum = 0;
    for (size_t i = 0; i < len; i++) sum += data[i];
    return sum;
}

// The Real DSP Function
void Calculate_Power_Quality(WaveformPacket_t* p)
{
    float32_t active_power_sum = 0.0f;
    float32_t v_max = 0.0f;
    float32_t i_max = 0.0f;

    float32_t temp_v_rms = 0.0f;
    float32_t temp_i_rms = 0.0f;
    float32_t temp_reactive = 0.0f;
    float32_t temp_thd_v = 0.0f;
    float32_t temp_thd_i = 0.0f;

    // 1. CONVERT, SCALE, AND FIND PEAKS
    for (uint16_t i = 0; i < SAMPLES; i++)
    {
        v_float[i] = (float32_t)p->voltage[i] * V_CALIBRATION_FACTOR;
        i_float[i] = (float32_t)p->current[i] * I_CALIBRATION_FACTOR;

        if (fabsf(v_float[i]) > v_max) v_max = fabsf(v_float[i]);
        if (fabsf(i_float[i]) > i_max) i_max = fabsf(i_float[i]);
    }

    // 2. RMS & CREST FACTOR
    arm_rms_f32(v_float, SAMPLES, &temp_v_rms);
    arm_rms_f32(i_float, SAMPLES, &temp_i_rms);

    p->v_rms = temp_v_rms;
    p->i_rms = temp_i_rms;

    p->crest_factor_v = (p->v_rms > 0.1f) ? (v_max / p->v_rms) : 0.0f;
    p->crest_factor_i = (p->i_rms > 0.01f) ? (i_max / p->i_rms) : 0.0f;

    // 3. POWER CALCULATIONS
    arm_dot_prod_f32(v_float, i_float, SAMPLES, &active_power_sum);
    p->active_power = active_power_sum / (float32_t)SAMPLES;
    p->apparent_power = p->v_rms * p->i_rms;

    p->power_factor = (p->apparent_power > 0.1f) ? (p->active_power / p->apparent_power) : 0.0f;
    if (p->power_factor > 1.0f) p->power_factor = 1.0f;
    if (p->power_factor < -1.0f) p->power_factor = -1.0f;

    float32_t q_sq = (p->apparent_power * p->apparent_power) - (p->active_power * p->active_power);
    arm_sqrt_f32((q_sq > 0.0f) ? q_sq : 0.0f, &temp_reactive);
    p->reactive_power = temp_reactive;

    // 4. FFT ON VOLTAGE AND CURRENT
    // (init once, not every call — arm_rfft_fast_init_f32 just fills a struct with twiddle
    //  factor pointers, it's wasted work to redo it on every single packet)
    static arm_rfft_fast_instance_f32 fft_inst;
    static uint8_t fft_initialized = 0;
    if (!fft_initialized) {
        arm_rfft_fast_init_f32(&fft_inst, SAMPLES);
        fft_initialized = 1;
    }

    arm_rfft_fast_f32(&fft_inst, v_float, fft_output_v, 0);
    arm_cmplx_mag_f32(fft_output_v, magnitudes_v, SAMPLES / 2);

    arm_rfft_fast_f32(&fft_inst, i_float, fft_output_i, 0);
    arm_cmplx_mag_f32(fft_output_i, magnitudes_i, SAMPLES / 2);

    // 5. FIND THE FUNDAMENTAL — full-spectrum search (bin 0 / DC excluded)
    // Voltage is used as the reference for the fundamental bin. Current is often far more
    // distorted (nonlinear loads, switching supplies) and its true peak bin can drift away
    // from the real fundamental, so anchoring both channels' harmonic numbering to the
    // voltage fundamental is the standard approach in power quality analyzers.
    float32_t max_mag = 0.0f;
    uint32_t fundamental_bin = 1;

    for (uint32_t b = 1; b < (SAMPLES / 2); b++) {
        if (magnitudes_v[b] > max_mag) {
            max_mag = magnitudes_v[b];
            fundamental_bin = b;
        }
    }

    // Parabolic interpolation across the 3 bins around the peak for sub-bin frequency
    // resolution. Raw bin spacing is SAMPLING_FREQ/SAMPLES ≈ 9.77 Hz here, which is coarse
    // enough that 49 Hz and 51 Hz could otherwise land in the same bin.
    float32_t bin_freq = SAMPLING_FREQ / (float32_t)SAMPLES;
    float32_t true_bin = (float32_t)fundamental_bin;
    if (fundamental_bin > 1 && fundamental_bin < (SAMPLES / 2 - 1)) {
        float32_t alpha = magnitudes_v[fundamental_bin - 1];
        float32_t beta  = magnitudes_v[fundamental_bin];
        float32_t gamma = magnitudes_v[fundamental_bin + 1];
        float32_t denom = (alpha - 2.0f * beta + gamma);
        if (fabsf(denom) > 1e-9f) {
            float32_t offset = 0.5f * (alpha - gamma) / denom;
            if (offset > 0.5f) offset = 0.5f;
            if (offset < -0.5f) offset = -0.5f;
            true_bin = (float32_t)fundamental_bin + offset;
        }
    }

    p->frequency = true_bin * bin_freq;
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

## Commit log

2026-06-20 Circuit sketches and new pcb design files were added
2026-07-02 Enhance README with detailed project information
    Expanded the overview and features of the Smart Power Quality Analyzer, detailing its architecture, key features, and contributions. Added sections on power quality analysis, user interface, connecti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
2026-07-21 Add smart power quality analyzer project
    [partitions.csv]
2026-07-21 Add STM32 SPI project files
2026-07-21 Final reports and media were added
    [partitions.csv]
2026-07-21 Add STM32 final project files
2026-07-21 Update README with STM32F4 and UART changes
2026-07-27 Replace altium.zip file with new_altium folder
    [ADS8588.SchDoc, EDR.PcbDoc, EDR.PrjPcb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]
2026-09-24 Correct STM32 model and communication interface in README
    Updated microcontroller references and communication interface details in the README.

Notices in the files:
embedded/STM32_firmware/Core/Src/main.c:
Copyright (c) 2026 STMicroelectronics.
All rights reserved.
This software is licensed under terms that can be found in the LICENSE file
